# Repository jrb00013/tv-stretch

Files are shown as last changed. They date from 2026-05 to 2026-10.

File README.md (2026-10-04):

# tv-stretch

Room-aware TV coordination: a **FastAPI** server plus **ESP32** nodes that attach to each TV’s HDMI CEC bus. The stack orchestrates which room is “active” and sends control-plane commands (power, input, CEC keys). It does **not** sync protected streaming playheads; see [docs/ARCHITECTURE.md](docs/ARCHITECTURE.md).

## Repository layout

| Path | Purpose |
|---|---|
| `docs/` | Architecture, BOM, component datasheets notes, CEC, mechanical |
| `hardware/kicad/` | KiCad 8 schematic and PCB |
| `hardware/cad/` | Enclosure source and `exports/enclosure.step` |
| `firmware/tv-stretch-node/` | ESP-IDF firmware (ESP32-C3 target) |
| `server/` | FastAPI + SQLite (SQLModel), WebSocket device gateway |

## Quickstart (API)

```bash
cd server
python3 -m venv .venv
source .venv/bin/activate
pip install -e ".[dev]"
export TV_STRETCH_DATABASE_URL="sqlite:///./tv_stretch.db"
uvicorn app.main:app --reload --host 0.0.0.0 --port 8000
```

Open `http://localhost:8000/` (redirects to the control UI) or `http://localhost:8000/docs` for OpenAPI.

**Browser control UI** (`/ui/`): sticky section nav, API **version chip** (from `/health/ready`), **diagnostics** (`GET /diagnostics/overview` and per-home **live** sockets), **spatial maps** + **occupancy** lab (`/spatial/maps`, `POST /presence/occupancy`), dark-themed **bootstrap**, authenticated **REST**, **app** and **device** WebSocket labs, **log** export (download + **Ctrl+Shift+S**) and clear (**Ctrl+Shift+L**). Assets: `server/static/css/`, `server/static/js/`, `server/static/assets/favicon.svg`. Full protocol: [docs/API.md](docs/API.md). Provisioning + OTA: [docs/PROVISIONING_AND_OTA.md](docs/PROVISIONING_AND_OTA.md).

Server package version is **0.6.1** (`pyproject.toml` / `TV_STRETCH_*` defaults).

### Coordinator capabilities

| Area | What it does | Key routes |
|---|---|---|
| Handoff | REST / app-WebSocket / sensor-driven handoffs, standby of other TVs | `POST /sessions/handoff`, `/ws/app` |
| Delivery | Every `command_batch` tracked to node acks, exponential-backoff retry, dead letters | `GET /sessions/batches` |
| Replay safety | `Idempotency-Key` on the mutating session endpoints | `Idempotency-Key:` header |
| Room policy | Per-room volume cap, mute-on-handoff, preferred input, standby opt-out | `GET/PUT/DELETE /rooms/{id}/policy` |
| Quiet hours | Per-home do-not-disturb window; people can override, sensors cannot | `GET/PUT/DELETE /quiet-hours` |
| Presence tuning | Dwell hysteresis + vacancy release so sensors do not thrash the TVs | `GET /presence/hysteresis` |
| Content | Catalogue behind `content_ref`, play stats, now-playing | `GET /content`, `GET /sessions/now-playing` |
| Firmware | Per-node rollout status against a target version | `GET/PUT/DELETE /ota/rollout` |
| Events | Time-window queries, cursor pagination, age-based pruning | `GET/DELETE /sessions/events` |
| Webhooks | Signed (HMAC) outbound events with retry and delivery stats | `GET/POST /webhooks` |
| Metrics | Prometheus text format: HTTP, sockets, batch depth, node health | `GET /metrics` |

### Environment variables

| Variable | Default | Purpose |
|---|---|---|
| `TV_STRETCH_PRESENCE_HANDOFF_MIN_CONFIDENCE` | `0.65` | Minimum occupancy confidence to trigger a handoff |
| `TV_STRETCH_PRESENCE_DWELL_SECONDS` | `0` (off) | Continuous occupancy required before a sensor-driven handoff |
| `TV_STRETCH_PRESENCE_DWELL_MAX_GAP_SECONDS` | `30` | Longer reporting gap restarts the dwell timer |
| `TV_STRETCH_PRESENCE_RELEASE_SECONDS` | `0` (off) | Sustained vacancy in the active room → TVs stand by |
| `TV_STRETCH_DATABASE_URL` | `sqlite:///./tv_stretch.db` | SQLAlchemy database URL |
| `TV_STRETCH_CORS_ORIGINS` | `*` | Comma-separated allowed origins |
| `TV_STRETCH_PUBLIC_BASE_URL` | `http://127.0.0.1:8000` | Base URL used in OTA manifest URLs |
| `TV_STRETCH_OTA_FIRMWARE_PATH` / `_VERSION` | — / `0.6.1` | Hosted firmware binary and the version it reports |
| `TV_STRETCH_MQTT_ENABLED` / `_BROKER_URL` / `_BROKER_PORT` / `_PREFIX` | `true` / `localhost` / `1883` / `tvstretch` | Optional MQTT mirroring |

Quiet hours and room policies are per-home rows configured over the API, not env vars.
Full protocol and semantics: [docs/API.md](docs/API.md).

From the repo root, `./scripts/dev.sh` or `make dev` runs uvicorn with a local SQLite DB (after `pip install -e ".[dev]"` in `server/`).

Optional env vars: copy `server/.env.example` → `server/.env`. Example curls for spatial + occupancy: `scripts/spatial-presence-examples.sh` (set `TOKEN`, optionally `BASE`).

**Breaking note (0.2+):** `Home` rows require `control_token`. Delete old `tv_stretch.db` or recreate homes after upgrading.

### Docker

```bash
docker compose up --build
```

API on `http://localhost:8000`. Mosquitto is included for optional MQTT experiments; the default device transport is WebSocket.

## Firmware

Requires [ESP-IDF](https://docs.espressif.com/projects/esp-idf/) v5.2+.

```bash
cd firmware/tv-stretch-node
idf.py set-target esp32c3
idf.py build
idf.py -p /dev/ttyUSB0 flash monitor
```

Set WiFi and server URL via `idf.py menuconfig` → **TV Stretch Node Configuration**, or NVS keys documented in `firmware/tv-stretch-node/README.md`.

## Hardware

- KiCad project: `hardware/kicad/tv-stretch-node/`
- Gerber export: see `hardware/kicad/tv-stretch-node/exports/README.md`
- Enclosure STEP: `hardware/cad/enclosure/exports/enclosure.step` (regenerate with `scripts/generate_enclosure_step.py` if needed)

## License

MIT — see [LICENSE](LICENSE).

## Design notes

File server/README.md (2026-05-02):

# tv-stretch server

FastAPI coordinator: REST for provisioning and session control; WebSockets for device command batches.

## Run locally

```bash
python3 -m venv .venv
source .venv/bin/activate
pip install -e ".[dev]"
export TV_STRETCH_DATABASE_URL="sqlite:///./tv_stretch.db"
uvicorn app.main:app --reload --host 0.0.0.0 --port 8000
```

## Docker

From repo root: `docker compose up --build`.

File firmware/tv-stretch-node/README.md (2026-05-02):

# tv-stretch-node firmware

ESP-IDF **5.2+** project targeting **ESP32-C3**.

## Build

```bash
export IDF_PATH=/path/to/esp-idf
. $IDF_PATH/export.sh
cd firmware/tv-stretch-node
idf.py set-target esp32c3
idf.py menuconfig   # TV Stretch Node Configuration
idf.py build
```

## Flash

```bash
idf.py -p /dev/ttyUSB0 flash monitor
```

## NVS keys (optional overrides)

Use `nvs_set_str` via a small flasher or `idf.py nvs-set` if configured:

| Key | Purpose |
|-----|---|
| `wifi_ssid` | WiFi SSID |
| `wifi_pass` | WiFi password |
| `ws_url` | `ws://host:8000/ws/device` |
| `api_key` | Device bearer token |
| `room_id` | UUID string |
| `home_id` | UUID string |

Namespace: `tvstretch`.

## Features (0.2)

- Wi‑Fi STA with **wait-for-IP** before WebSocket connect.
- **Status LED** pulse on each `command_batch` (Kconfig `TVS_STATUS_LED_ENABLE` / GPIO).
- CEC commands: `cec_broadcast_ping`, `cec_active_source` (opcode `0x82` + physical address), `cec_standby`, `cec_send_raw`, `policy` (logged), `noop`.
- Sends **ack** after each batch with server `batch_id`.
- Reports `CONFIG_TVS_FW_VERSION` in `hello`.

## WebSocket protocol

See [docs/ARCHITECTURE.md](../../docs/ARCHITECTURE.md) and [docs/API.md](../../docs/API.md). Messages are JSON with `"v":1`.

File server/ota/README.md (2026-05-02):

# OTA artifacts (optional)

Place a built ESP-IDF binary here (e.g. copy `build/tv-stretch-node.bin` after `idf.py build`) and point the server at it:

```bash
export TV_STRETCH_OTA_FIRMWARE_PATH="$PWD/server/ota/tv-stretch-node.bin"
export TV_STRETCH_OTA_FIRMWARE_VERSION="0.3.0"
export TV_STRETCH_PUBLIC_BASE_URL="http://192.168.1.10:8000"
```

- `GET /ota/manifest` returns JSON with `version` and `url` for devices.
- `GET /ota/firmware.bin` streams the file.

Devices can pull via coordinator command:

```json
{"cmd":"ota_pull","payload":{"manifest_url":"http://192.168.1.10:8000/ota/manifest","only_if_version_differs":true}}
```

or direct URL:

```json
{"cmd":"ota_pull","payload":{"url":"http://192.168.1.10:8000/ota/firmware.bin"}}
```

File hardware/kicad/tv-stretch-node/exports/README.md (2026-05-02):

# KiCad exports

## Gerbers

From KiCad **pcbnew**:

1. **File → Fabrication Outputs → Gerbers (.ger)**
2. Include: `F.Cu`, `B.Cu`, `Edge.Cuts`, `F.Mask`, `B.Mask`, `F.Silkscreen`, `B.Silkscreen`
3. **Drill Files** separately if required by fab

Optional: `kicad-cli pcb export gerbers ...` (KiCad 7+ CLI).

## STEP (PCB 3D)

**File → Export → STEP** with component models enabled once footprints are placed.

Save as `exports/pcb.step` (gitignored if large) or attach to releases.

## Netlist

Use **Tools → Update PCB from Schematic** after completing symbols and footprints.

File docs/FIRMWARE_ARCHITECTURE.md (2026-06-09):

# tv-stretch-node Firmware Architecture

**Target:** ESP32-C3 (RISCV 32-bit single-core, 400 KB SRAM, 4 MB flash)  
**Framework:** ESP-IDF 5.2+  
**Protocol:** CEC bit-bang on GPIO + WebSocket JSON control-plane

---

## 1. System Overview

Each TV in a room gets an ESP32-C3 node wired to its HDMI CEC pin (pin 13). The node connects to the coordinator server via WebSocket and executes HDMI-CEC commands over a bit-banged GPIO line. There is no HDMI input switching or EDID emulation — this is purely a control-plane bridge.

```
┌─────────────────┐     WebSocket      ┌──────────────────┐
│  Coordinator    │ ◄────────────────► │  ESP32-C3 Node   │
│  (FastAPI)      │   JSON/v1 protocol │  (tv-stretch-node)│
└─────────────────┘                    └────────┬─────────┘
                                                 │ GPIO (open-drain)
                                                 ▼
                                         ┌──────────────────┐
                                         │  TV HDMI CEC pin │
                                         └──────────────────┘
```

---

## 2. State Machine

The node lifecycle is driven by a finite state machine in `core/tvs_state.c`:

```
COLD_START
    │
    ├── PROVISIONING ──── (SoftAP + HTTP portal, blocks)
    │
    ├── WIFI_CONNECT ──── WiFi STA started
    │       │
    │       └── WIFI_WAIT ──── waiting for DHCP
    │               │
    │               └── WS_CONNECT ──── WebSocket client started
    │                       │
    │                       ├── WS_CONNECTED ──── hello sent, ready
    │                       │
    │                       └── DISCONNECTED ──── WS dropped, reconnecting
    │
    ├── ERROR ──── unrecoverable fault
    │
    └── DEEP_SLEEP ──── low-power mode (future)
```

State transitions drive LED patterns and enable/disable subsystems.

---

## 3. Boot Sequence

```
app_main()
    │
    ├── nvs_flash_init()
    │       └── NVS recovery (erase + retry if corrupted)
    │
    ├── tvs_led_init() ──── LED task starts (BOOT pattern)
    │
    ├── tvs_watchdog_init() ──── esp_task_wdt, 30s timeout
    │
    ├── tvs_state_init() ──── state machine + change callback
    │
    ├── tvs_cec_init() ──── CEC TX GPIO (open-drain)
    ├── tvs_cec_rx_init() ──── CEC RX GPIO interrupt + ring buffer
    ├── tvs_cec_proto_init() ──── CEC protocol parser
    │
    ├── tvs_cmd_queue_init() ──── command queue with retry
    ├── tvs_health_init() ──── health counters
    │
    ├── esp_netif_init() + esp_event_loop_create_default()
    │
    ├── [CONFIG_TVS_HTTP_PROVISIONING] ──Provisioning check──┐
    │       └── NVS provisioned?                              │
    │           ├── NO  → tvs_prov_run_http_setup()           │
    │           │         (state → PROVISIONING)              │
    │           └── YES → continue                            │
    │                                                         │
    ├── Read NVS (tvstretch namespace)                       │
    │       ├── wifi_ssid / wifi_pass                        │
    │       ├── ws_url / api_key                             │
    │       ├── room_id / home_id                            │
    │                                                         │
    ├── tvs_wifi_start_sta(ssid, pass)                       │
    │       └── state → WIFI_CONNECT                         │
    │                                                         │
    ├── tvs_cec_rx_start() ──── enable CEC RX ISR            │
    │                                                         │
    ├── cmd_queue_task ──── processes queued commands         │
    │                                                         │
    ├── [CONFIG_TVS_OTA_AUTO_CHECK_ON_BOOT]                  │
    │       └── Spawns boot_ota_task (optional)              │
    │                                                         │
    ├── tvs_ws_start() ──── WebSocket client                 │
    │       └── state → WS_CONNECT                            │
    │       └── on_connect → state → WS_CONNECTED + send hello│
    │                                                         │
    ├── heartbeat_task ── every 25s if WS_CONNECTED          │
    ├── health_task ──── every 60s logs telemetry            │
    │                                                         │
    └── main loop ──── feeds watchdog every 5s               │
```

---

## 4. Module Map

| Module | File(s) | Purpose |
|---|---|---|
| **Main** | `app_main.c` | Boot sequence, task spawning, state wiring |
| **State Machine** | `core/tvs_state.c`, `core/tvs_state.h` | Finite state machine with change callback |
| **Command Queue** | `core/tvs_cmd_queue.c`, `core/tvs_cmd_queue.h` | Retry-capable command queue with ACK/NACK |
| **Protocol** | `proto/tv_stretch_proto.h` | Constants (`TVS_PROTO_VER`), message type enum, command struct |
| **CEC TX** | `cec/cec_bitbang.c`, `cec/cec_bitbang.h` | Bit-banged CEC transmit using esp_rom_delay_us |
| **CEC RX** | `cec/cec_rx.c`, `cec/cec_rx.h` | GPIO interrupt edge capture + ring buffer + software decode |
| **CEC Proto** | `cec/cec_proto.c`, `cec/cec_proto.h` | CEC opcode parsing, device discovery, bus scan |
| **WiFi** | `net/tvs_wifi.c`, `net/tvs_wifi.h` | STA mode with event-driven connect/reconnect |
| **WebSocket** | `net/ws_client.c`, `net/ws_client.h` | esp_websocket_client wrapper, header injection, connect callback |
| **OTA** | `ota/tvs_ota.c`, `ota/tvs_ota.h` | HTTP/HTTPS OTA from URL or manifest JSON |
| **LED** | `sys/tvs_led.c`, `sys/tvs_led.h` | LED pattern engine (BOOT, CONNECTING, CONNECTED, etc.) |
| **Health** | `sys/tvs_health.c`, `sys/tvs_health.h` | Telemetry counters (RSSI, frame counts, heap, uptime) |
| **Watchdog** | `sys/tvs_watchdog.c`, `sys/tvs_watchdog.h` | ESP-TASK-WDT wrapper |
| **Provisioning** | `prov/prov_http.c`, `prov/prov_http.h` | SoftAP + HTTP capture portal |
| **NVS** | `prov/tvs_nvs.c`, `prov/tvs_nvs.h` | Provisioned-state check (`nvs_get_u8`) |

---

## 5. CEC Driver Design

### 5.1 Transmit (`cec_bitbang.c`)

Implements the HDMI-CEC physical layer using bit-banged GPIO with spin-loop timing.

#### Timing (microseconds)

| Signal | Low (us) | High (us) |
|---|---|---|
| Start bit | 3700 | 800 |
| Logic 0 | 1500 | 900 |
| Logic 1 | 600 | 600 |

#### Frame format

```
[Start Bit] [Header Byte: initiator<<4 | destination] [Data Bytes...] [EOM bit per byte]
```

- Each byte is 8 bits LSB-first + 1 EOM bit + ACK slot
- The follower is expected to pull the ACK slot low; this driver uses a fixed delay for the ACK window
- No arbitration or retry logic (single-talker topology assumed)
- Before each frame, `tvs_cec_set_tx_active(true)` suppresses RX echo detection

### 5.2 Receive (`cec_rx.c`)

GPIO interrupt-based edge capture with software bit decoding.

- GPIO `INTR_ANYEDGE` ISR pushes timestamps into a 128-entry ring buffer
- Dedicated decode task (`cec_rx`) pops edges and reconstructs bits/frames
- Start bit detection (`low=3000-4500us, high=600-1100us`) triggers frame assembly
- Frame timeout after 5ms of bus inactivity
- `s_tx_active` flag suppresses echo during local TX
- Completed frames are passed to the registered callback (`tvs_cec_rx_cb`)
- Frame counter exposed for health telemetry

### 5.3 Protocol Layer (`cec_proto.c`)

Parses received CEC frames and maintains a device table:

- Tracks 16 logical addresses with physical address, device type, OSD name, vendor ID, power status
- Responds to `REPORT_PHYSICAL_ADDR`, `REPORT_POWER_STATUS`, `SET_OSD_NAME`, `DEVICE_VENDOR_ID`, `ACTIVE_SOURCE`, `STANDBY`
- Bus scan: polls all 15 addresses with `GIVE_PHYSICAL_ADDR`, `GIVE_OSD_NAME`, `GIVE_DEVICE_POWER_STATUS`
- Frames that are not protocol-internal are forwarded to the application callback

---

## 6. WebSocket Protocol

### Connection

The node connects to `ws://<coordinator>/ws/device` with custom HTTP headers:

```
Authorization: Bearer <api_key>
X-TV-Stretch-Home: <home_uuid>
X-TV-Stretch-Room: <room_uuid>
```

### Messages (all JSON with `"v": 1`)

**Node → Server:**

| Type | Frequency | Payload |
|---|---|---|
| `hello` | Once on connect | `{node: {room_id, home_id, fw}}` |
| `heartbeat` | Every 25s | None |
| `ack` | After each batch | `{batch_id, ok}` |
| `event` | On CEC RX / errors | `{payload: {kind, raw}}` |

**Server → Node:**

| Type | Purpose |
|---|---|
| `command_batch` | Array of commands with batch_id |

---

## 7. Command Dispatch

Commands arrive in `command_batch` messages and are enqueued into `tvs_cmd_queue`. The `cmd_queue_task` dequeues and dispatches them:

| cmd | Action |
|-----|---|
| `noop` | Log, no-op |
| `policy` | Log (server-side enforcement) |
| `ota_pull` | Start OTA from URL or manifest |
| `cec_broadcast_ping` | Send 0x83 frame |
| `cec_standby` | Send `<Standby>` (0x36) |
| `cec_active_source` | Send `<Active Source>` (0x82 + addr) |
| `cec_user_control` | Send `<User Control Pressed>` (0x44 + key) |
| `cec_set_stream_path` | Send `<Set Stream Path>` (0x86 + addr) |
| `cec_send_raw` | Send arbitrary CEC frame from byte array |
| `scan_bus` | Initiate CEC bus device discovery |

After all commands in a batch are processed, an `ack` is sent back.

---

## 8. LED Patterns

| State | Pattern |
|---|---|
| BOOT | Fast blink (200ms on/off) |
| CONNECTING | Slow blink (50ms on, 950ms off) |
| CONNECTED | Long pulse (100ms on, 2900ms off) |
| COMMAND | Quick flash (40ms on) |
| ERROR | Rapid blink (100ms on/off) |
| OTA | Toggle (500ms on/off) |
| OFF | Solid off |

---

## 9. Health Telemetry

The `health_task` logs every 60s (configurable via `TVS_HEALTH_INTERVAL`):

- Uptime in seconds
- WiFi RSSI
- CEC TX/RX frame counts
- WebSocket reconnection count
- Command queue depth
- Free heap / minimum free heap

---

## 10. OTA Update

Two mechanisms:

1. **Direct URL:** `ota_pull` with `{"url": "http://.../firmware.bin"}`  
   Downloads and applies via `esp_https_ota`

2. **Manifest URL:** `ota_pull` with `{"manifest_url": "http://.../manifest.json"}`  
   Fetches `{"version": "x.y.z", "url": "..."}`, optionally skips if version matches `CONFIG_TVS_FW_VERSION`

OTA uses dual-OTA partition table (2 × 1.66 MB slots). On success, `esp_restart()` boots into the new slot.

---

## 11. Provisioning

Optional HTTP-based provisioning (disabled by default, enable via `TVS_HTTP_PROVISIONING` Kconfig):

1. On first boot (NVS `provisioned != 1`), starts SoftAP `tv-stretch-setup`
2. HTTP server on `192.168.4.1:80` serves a capture portal form
3. POST `/save` writes WiFi/coordinator settings to NVS and sets `provisioned=1`
4. Device reboots into normal operation

---

## 12. Watchdog

ESP-TASK-WDT with configurable timeout (default 30s). The main loop feeds every 5s. If any task hangs for longer than the timeout, the watchdog panics and triggers a reboot.

---

## 13. Memory & Task Layout

| Task | Stack | Priority | Function |
|---|---|---|---|
| `main` | (default) | 1 | Boot, then watchdog feed loop |
| `tvs_led` | 2048 | 1 | LED pattern oscillator |
| `cec_rx` | 4096 | 8 | CEC edge decode |
| `cmdq` | 4096 | 6 | Command queue dispatch |
| `boot_ota` | 8192 | 3 | Boot-time OTA check (optional) |
| `ota` | 10240 | 5 | OTA download task |
| `hb` | 3072 | 5 | Heartbeat sender |
| `health` | 3072 | 2 | Telemetry logger |
| WiFi/WS | (IDF internal) | — | Event loop, WebSocket RX |

---

## 14. Build & Test

```bash
# Standard build
idf.py set-target esp32c3
idf.py menuconfig
idf.py build

# Flash and monitor
idf.py -p /dev/ttyUSB0 flash monitor

# Unity unit tests (on-target)
idf.py test

# Integration tests (requires pytest-embedded)
pip install pytest-embedded-serial-esp
pytest firmware/tv-stretch-node/pytest_tv_stretch_node.py \
    --embedded-services esp,idf \
    --app firmware/tv-stretch-node/build
```

---

## 15. Configuration (Kconfig)

See `main/Kconfig.projbuild` for all options. Key settings:

| Option | Default | Notes |
|---|---|---|
| `TVS_CEC_LOGICAL_ADDR` | 4 | CEC logical address claimed on bus |
| `TVS_CEC_GPIO` | 4 | CEC output pin |
| `TVS_CEC_RX_ENABLE` | y | Enable CEC receive path |
| `TVS_STATUS_LED_GPIO` | 8 | Activity LED pin |
| `TVS_HEALTH_INTERVAL` | 60s | Health telemetry log interval |
| `TVS_WATCHDOG_TIMEOUT` | 30s | Task watchdog timeout |
| `TVS_FW_VERSION` | 0.4.0 | Semver reported to coordinator |
| `TVS_HTTP_PROVISIONING` | n | Enable SoftAP setup portal |
| `TVS_OTA_AUTO_CHECK_ON_BOOT` | n | Auto-OTA on version mismatch |

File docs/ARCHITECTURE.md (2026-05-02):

# Architecture

## Goals

- **Coordinator**: single source of truth for which **room** should have the “focused” TV.
- **Nodes**: one device per TV, connected to the **HDMI CEC** line, receiving commands over **WiFi** (WebSocket to the server).
- **Clients**: apps over **`/ws/app`**, REST handoffs, or **optical / SLAM pipelines** via **`POST /presence/occupancy`** (room + confidence).

## Honesty boundary

Commercial streaming apps do not expose a supported API for **frame-accurate** resume across TVs. This project implements:

- Session metadata you control (`content_ref`, `transport`).
- TV **control plane**: CEC messages, power, input selection.
- Orchestration: **standby or focus** policies when the active room changes.

## System diagram

```mermaid
flowchart TB
  subgraph cloud [Home_LAN]
    API[FastAPI_server]
    DB[(SQLite)]
    API --> DB
  end
  Phone[Mobile_or_sensor_client]
  Slam[Optical_SLAM_or_presence_rig]
  N1[Node_room_A]
  N2[Node_room_B]
  TV1[TV_A]
  TV2[TV_B]
  Phone -->|REST_or_WS| API
  Slam -->|POST_/presence/occupancy| API
  N1 <-->|WSS_device| API
  N2 <-->|WSS_device| API
  N1 <-->|HDMI_CEC| TV1
  N2 <-->|HDMI_CEC| TV2
```

## Message flow

1. Client sets **active session** (`home_id`, `active_room_id`, optional `content_ref`) — via REST, **`/ws/app`**, or **`POST /presence/occupancy`** when localization confidence exceeds the configured threshold.
2. **Coordinator** computes a **command batch**:
   - `focus` for the node in `active_room_id`.
   - Optional `standby_others` or `cec_user_control` for non-active nodes (policy flags).
3. Server pushes JSON over **`/ws/device`** to connected nodes for that `home_id`.
4. Node applies CEC or logs if CEC is disabled in dev.

## WebSocket protocol (summary)

- **Device → server**: `hello` (api_key, node_id, firmware version), `heartbeat`, `ack`, `event` (e.g. `cec_rx` debug).
- **Server → device**: `command_batch` with ordered commands: `cec_send`, `power_toggle`, `noop`, etc.

Schema version field: `v` in each message (currently `1`).

## Security

- **Per-node API key** (stored in NVS). Rotate via re-provisioning.
- **Home `control_token`**: returned on `POST /homes` and `POST /bootstrap/...`; required for **`/ws/app`** (presence / handoff from a companion app). Treat like a password; rotate with `POST /homes/{id}/rotate-control-token`.
- Production: TLS termination (reverse proxy), no anonymous MQTT.

## Risks

- **CEC** behavior varies by TV vendor; physical address and opcodes may need tuning.
- **HDMI compliance** and trademark if you productize a dongle—consult qualified legal/compliance review.
- WiFi latency and reconnects: firmware must **buffer** one batch and **dedupe** by `batch_id`.

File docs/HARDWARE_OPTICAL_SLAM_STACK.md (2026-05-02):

# Optical SLAM, room occupancy, and the coordinator

This document ties **custom PCB / optical sensing**, **house-scale mapping (SLAM or surrogate)**, **person-in-room estimation**, and the **tv-stretch FastAPI server** so TVs follow the user via CEC handoffs.

It is an architecture guide—not a turnkey SLAM implementation. Pick compute where your algorithm requires it (often **SBC class**, not the ESP32 CEC dongle alone).

## Roles

| Layer | Responsibility |
|---|---|
| **Mapping** | Produce a metric or topological map with **room segments** aligned (manually or automatically) to logical `Room` UUIDs already provisioned in the coordinator (`POST /rooms`, bootstrap). |
| **Localization** | Estimate camera / rig pose in the map; derive **which room polygon** contains the user (point-in-polygon or classifier). |
| **Confidence** | Emit a scalar **0–1** confidence before acting (tracking quality, occlusion, multi-hypothesis spread). |
| **Coordinator** | `POST /presence/occupancy` with `room_id` + `confidence`. Above `TV_STRETCH_PRESENCE_HANDOFF_MIN_CONFIDENCE`, runs the same path as REST/WebSocket handoff → **`command_batch`** to HDMI nodes → **switch inputs / policy** on TVs. |
| **CEC nodes** | Existing **tv-stretch-node** firmware on ESP32-C3 (see KiCad project); unchanged protocol over `/ws/device`. |

## Hardware paths (examples)

### A — Wearable / handheld rig (RGB-D or stereo + IMU)

- **Compute:** Raspberry Pi 5 / Jetson Orin Nano / x86 NUC for heavy VIO/SLAM if needed.
- **Sensors:** Stereo pair or RGB-D (e.g. Intel RealSense class), **IMU** for scale and gravity alignment.
- **Radio:** Wi‑Fi to LAN; HTTPS or WSS to coordinator (browser-grade TLS via reverse proxy).
- **Custom PCB:** Sensor bracket + **USB3** hub + IMU on **I²C** to the SBC; optional battery gauge.

### B — Fixed ceiling / wall optical nodes (no full SLAM on device)

- **Per-room** depth blob or low-res occupancy grid fused on a **home server**; server-side SLAM optional.
- **Optical:** ToF arrays (e.g. **VL53L5CX**), mmWave presence (non-optical but common pairing), or narrow-FOV IR grids.
- **MCU:** ESP32-S3 for aggregation + Wi‑Fi; **not** responsible for full-house SLAM unless map is trivial.

### C — Cartographer-style LiDAR + odometry (mobile base)

- **2D LiDAR** + wheel odometry or IMU; output pose to mapping stack; room IDs assigned when crossing thresholds / doors (still map to coordinator `room_id` UUIDs).

## Map ↔ server contract

1. **Provision rooms** in the coordinator (`POST /bootstrap/home-with-rooms` or `/rooms`) so each physical room has a **stable UUID**.
2. **Upload spatial metadata** (optional but recommended): `POST /spatial/maps` with JSON under `slam.v1` (or your schema string). Store polygons, adjacency, or vendor SLAM export references for debugging and alignment.
3. **Runtime:** localization stack selects **one `room_id`** + **confidence** → `POST /presence/occupancy`.

Payload shape is intentionally loose: your SLAM stack owns the JSON under `payload`; the server stores it opaquely for tooling.

## Software integration

- **Auth:** Same **`X-Control-Token`** as other home APIs (treat like a password on TLS inside LAN).
- **Threshold:** `TV_STRETCH_PRESENCE_HANDOFF_MIN_CONFIDENCE` (default **0.65**) suppresses flaky switches.
- **Displays:** Handoff path already issues **CEC** commands via nodes; tune coordinator policies (`standby_others`) for multi-TV homes.

## Physical / safety

- **HDMI CEC** varies by TV vendor—expect lab tuning (see [CEC_NOTES.md](CEC_NOTES.md)).
- **Privacy:** cameras and continuous localization carry consent and retention obligations—document your policy.

## Related docs

- [COMPONENTS_HARDWARE.md](COMPONENTS_HARDWARE.md) — tv-stretch-node BOM-level parts.
- [BOM.md](BOM.md) — optional presence/SLAM companion bill of materials.
- [ARCHITECTURE.md](ARCHITECTURE.md) — system diagram including occupancy path.
- [API.md](API.md) — `/spatial/*`, `/presence/occupancy`.

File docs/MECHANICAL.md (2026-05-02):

# Mechanical — enclosure

## Concept

**Inline puck** enclosure: PCB + HDMI **receptacle** faces one direction; **short pigtail** or second HDMI exits toward the TV. Two **shell halves** (top/bottom) with **snap clips** or **M2 standoffs** (optional).

## Files

| File | Description |
|---|---|
| `hardware/cad/enclosure/tv_stretch_enclosure.py` | build123d source (Python) |
| `hardware/cad/enclosure/exports/enclosure.step` | Hollow shell (outer box minus cavity) for printing / machining |

## Regenerating STEP

```bash
pip install build123d
python3 scripts/generate_enclosure_step.py
```

Default outer box (placeholder geometry) targets ~**80 × 40 × 22 mm**; edit parameters in the script to match your PCB.

## 3D printing

- **Orientation:** Largest flat face on build plate; avoid overhangs on clip features.
- **Tolerance:** Add **0.25–0.4 mm** clearance between shell and connector bodies.
- **Material:** PETG or ABS for heat near TV vents; PLA acceptable for prototypes.

## Strain relief

Use a **zip tie channel** around the HDMI pigtail exit (parametric in script) or heat-shrink anchor.

## KiCad PCB STEP

When the PCB is routed in KiCad: **File → Export → STEP** (include components). Store under `hardware/kicad/tv-stretch-node/exports/` if desired.

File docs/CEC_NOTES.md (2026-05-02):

# HDMI-CEC notes (tv-stretch-node)

## Pin reference (Type A HDMI)

| Pin | Name | Node connection |
|-----|---|---|
| 13 | CEC | MCU GPIO (open-drain), ESD diode |
| 17 | DDC/CEC GND | Ground |
| 18 | +5V | Optional sense / tie per design |

**Do not** connect TMDS pairs to the MCU; this design is **CEC-only**, not a video path.

## Electrical

- CEC is **single-wire**, **open-drain**, typically **3.3 V** I/O on modern implementations.
- Bit timing: start bit + data blocks per **HDMI 1.4b / CEC 1.4** (Consult HDMI Licensing / IEC 62388-1 for product compliance).
- Use **scope or logic analyzer** when bringing up a new TV.

## Firmware subset

The in-tree driver implements a **minimal** subset sufficient for demos:

- Low-level **start bit**, **byte TX/RX** with ACK bit handling (simplified).
- Helpers for **broadcast** and **directed** frames.
- Example opcodes: `<Give Physical Address>`, `<Report Physical Address>`, `<Active Source>`, `<Set Stream Path>`, `<Standby>`, `<User Control Pressed>` (power, select).

TVs may require correct **logical** and **physical** addresses. Set `physical_address` in Kconfig to match topology (e.g. `0x2000`).

## Compatibility

- Some TVs disable CEC unless enabled in menus (Samsung Anynet+, Sony Bravia Sync, etc.).
- AVRs in the path change routing; you may need to address the **receiver** instead of the TV.

## References (external)

- Community implementations (license differs): ESPHome native HDMI-CEC projects.
- HDMI organization specifications (paid / license agreement) for shipping products.

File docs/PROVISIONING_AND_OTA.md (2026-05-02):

# Provisioning and OTA

## HTTP provisioning (ESP32)

Enable **Component config → TV Stretch Node Configuration → First-boot SoftAP + HTTP provisioning UI**.

On first boot (NVS key `provisioned` ≠ 1), the device starts an access point:

- SSID / password: Kconfig `TVS_PROV_AP_SSID` / `TVS_PROV_AP_PASS` (defaults `tv-stretch-setup` / `tvstretch1`).
- Join from a phone or laptop, open **http://192.168.4.1**
- Submit Wi-Fi credentials, `ws_url` (`ws://…/ws/device`), node `api_key`, `home_id`, `room_id`.
- Device writes NVS namespace `tvstretch`, sets `provisioned=1`, reboots into STA mode.

Disable provisioning in production firmware builds once nodes are flashed, or rely on pre-provisioned NVS.

## OTA partitions

`firmware/tv-stretch-node/partitions.csv` defines **dual OTA** app slots. Flash with `idf.py flash` as usual; the running image must be linked for OTA (see ESP-IDF OTA docs).

`sdkconfig.defaults` sets `CONFIG_ESP_HTTPS_OTA_ALLOW_HTTP=y` so **LAN HTTP** URLs work. Do not expose unauthenticated OTA endpoints on the public internet.

## Coordinator OTA

See [server/ota/README.md](../server/ota/README.md). Configure `TV_STRETCH_OTA_FIRMWARE_PATH` and `TV_STRETCH_PUBLIC_BASE_URL`.

## Device-side triggers

- **Boot:** optional `TVS_OTA_BOOT_MANIFEST_URL` + `TVS_OTA_AUTO_CHECK_ON_BOOT` (off by default).
- **Command:** `ota_pull` with `url` or `manifest_url` (see server README).

Firmware version string comes from Kconfig `TVS_FW_VERSION` and is compared to manifest `version` when using `only_if_version_differs`.

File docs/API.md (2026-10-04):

# HTTP and WebSocket API

Base URL: `http://localhost:8000` (or your host). OpenAPI UI: `/docs`. Root `/` redirects to `/ui/` (browser lab).

## Authentication model

- **Nodes** (TV hardware): `Authorization: Bearer <node_api_key>` and `X-TV-Stretch-Home: <home_uuid>` on **`/ws/device`**.  
  For **browser testing** (no custom headers), the same credentials may be passed as query parameters:  
  `ws://host/ws/device?home_id=<uuid>&token=<api_key>` (or `api_key=` instead of `token=`).

- **Apps** (phone / automation): `X-Control-Token: <home.control_token>` on REST routes under `/homes`, `/rooms`, `/nodes`, `/sessions`, `/spatial`, `/presence`, etc.

- **App WebSocket** `/ws/app`: `Authorization: Bearer <control_token>` + `X-TV-Stretch-Home: <home_uuid>`, **or** query params `?home_id=<uuid>&token=<control_token>` (required for browsers).

REST endpoints for provisioning (`POST /homes`, `POST /bootstrap/...`) are unauthenticated by default (home LAN / dev). Put the API behind a reverse proxy and TLS before exposing to the internet.

## Bootstrap a home

```bash
curl -sS -X POST http://localhost:8000/bootstrap/home-with-rooms \
  -H 'Content-Type: application/json' \
  -d '{"home_name":"loft","room_names":["living","kitchen","bedroom"]}'
```

Save `home.control_token`, `home.id`, and each `rooms[].id`.

## Register a node per TV

Requires the home control token:

```bash
curl -sS -X POST http://localhost:8000/nodes/register \
  -H 'Content-Type: application/json' \
  -H "X-Control-Token: <CONTROL_TOKEN>" \
  -d '{"room_id":"<ROOM_UUID>","name":"living-tv"}'
```

Save `api_key` into firmware NVS (or Kconfig for dev).

## Handoff (REST)

```bash
curl -sS -X POST http://localhost:8000/sessions/handoff \
  -H 'Content-Type: application/json' \
  -H "X-Control-Token: <CONTROL_TOKEN>" \
  -d '{"active_room_id":"<ROOM_UUID>","content_ref":"demo","standby_others":true}'
```

- `standby_others` (default `true`): when true, the coordinator emits a `policy` command for non-active TVs; when `false`, that step is skipped.

Response includes `batch_id` and expanded `commands` pushed to connected nodes.

## Handoff (app WebSocket)

Connect to `ws://localhost:8000/ws/app` with headers or `?home_id=&token=` as above.

Send presence:

```json
{"v":1,"type":"presence","active_room_id":"<ROOM_UUID>","content_ref":"optional","standby_others":true}
```

Optional: query current session state without HTTP:

```json
{"v":1,"type":"get_session"}
```

Server replies:

```json
{"v":1,"type":"session_state","home_id":"...","active_room_id":null,"content_ref":null,"updated_at":null}
```

After a successful presence handoff:

```json
{"v":1,"type":"handoff_applied","batch_id":"..."}
```

Ping:

```json
{"v":1,"type":"ping"}
```

→ `{"v":1,"type":"pong"}`

## Device WebSocket protocol

Devices connect to `ws://host/ws/device` with node `api_key` and home id (headers **or** query params as above).

**Device → server**

| type | Purpose |
|---|---|
| `hello` | First contact; may include `node.fw`, `node.room_id`, `node.home_id`. Updates `last_seen_at` and firmware version. |
| `heartbeat` | Periodic liveness; updates `last_seen_at`. |
| `ack` | After executing a `command_batch`: `batch_id`, `ok`. Logged as `device_ack`. |
| `event` | Debug / vendor hooks; payload stored in `EventLog` as `device_event`. |

**Server → device**

- `command_batch`: `{ "v":1, "type":"command_batch", "batch_id":"...", "commands":[...] }`

Schema version field: `v` (currently `1`).

## Diagnostics

- `GET /diagnostics/overview` — counts + WebSocket snapshot (connected device nodes per home).
- `GET /diagnostics/homes/{home_id}/live` — connected device sockets for that home.
- `GET /health` — liveness.
- `GET /health/ready` — DB reachability smoke check. JSON includes `version` and `presence_handoff_min_confidence` (same default as `TV_STRETCH_PRESENCE_HANDOFF_MIN_CONFIDENCE`, for UI / rig tuning).

## Webhooks

Push home events to your own HTTP endpoint (Home Assistant, a shell script, a cloud function).
Requires `X-Control-Token`. Registering an endpoint requires the control token, so only the
home owner can make the server issue outbound requests — bind that thinking to your threat
model if you ever expose the token.

| Route | Purpose |
|---|---|
| `POST /webhooks` | Register an endpoint → `201` with the **signing secret shown once** |
| `GET /webhooks`, `GET /webhooks/{id}` | List / read (never includes the secret) |
| `PATCH /webhooks/{id}` | Change `url`, `events`, `enabled` |
| `DELETE /webhooks/{id}` | Remove |
| `POST /webhooks/{id}/rotate-secret` | New secret; old signatures stop verifying |
| `POST /webhooks/{id}/test` | Send a signed `test` delivery now |

```bash
curl -sS -X POST http://localhost:8000/webhooks \
  -H 'Content-Type: application/json' -H "X-Control-Token: <CONTROL_TOKEN>" \
  -d '{"url":"https://homeassistant.local/api/tv-stretch","events":["handoff","power"]}'
```

Events: `handoff`, `power`, `cec_key`, `input_select`, `standby_all`, `handoff_suppressed`,
`command_batch_failed`. An **empty `events` list receives everything**. Unknown names → `422`.
URLs must be `http`/`https` with a host.

Payload:

```json
{
  "event": "handoff",
  "home_id": "…",
  "sent_at": "2026-06-09T21:03:48Z",
  "data": {"batch_id": "…", "room_id": "…", "content_ref": "netflix:show-1", "source": "api"}
}
```

Headers: `X-TV-Stretch-Signature`, `X-TV-Stretch-Timestamp`, `X-TV-Stretch-Event`,
`X-TV-Stretch-Delivery`.

Verify with `hmac.compare_digest` over **`timestamp.body`**:

```python
expected = "sha256=" + hmac.new(secret.encode(), f"{timestamp}.{body}".encode(), hashlib.sha256).hexdigest()
ok = hmac.compare_digest(expected, headers["X-TV-Stretch-Signature"])
```

Binding the timestamp into the signature is what makes a captured request unusable when
replayed. Reject timestamps more than ~5 minutes old.

Delivery behaviour:

- **Queued, never awaited by the request.** A slow or dead receiver cannot add latency to a
  TV handoff; a background worker drains the queue.
- Retries: 3 attempts with exponential backoff (0.5s, 1s) on transport errors and `5xx`.
  **A `4xx` is not retried** — the receiver rejected the request, and repeating it will not
  help.
- Per-endpoint `last_status`, `last_error`, `success_count`, `failure_count` and
  `last_delivery_at` are recorded on every delivery, so a dead receiver is visible via
  `GET /webhooks` rather than silently dropping events.
- Uses the stdlib `urllib` (in a thread), so delivery adds no runtime dependency.

## Metrics

`GET /metrics` — Prometheus text exposition format (`text/plain; version=0.0.4`).
Unauthenticated, like `/health` and `/diagnostics/overview`: expose it on an internal
interface or behind the reverse proxy, not on the open internet.

| Series | Type | Labels |
|---|---|---|
| `tv_stretch_http_requests_total` | counter | `method`, `path`, `status` |
| `tv_stretch_http_request_duration_seconds` | histogram | `path` |
| `tv_stretch_build_info` | gauge | `version` |
| `tv_stretch_ws_connections` | gauge | `type` = `device` \| `app` |
| `tv_stretch_command_batches` | gauge | `status` = `pending` \| `completed` \| `dead_letter` |
| `tv_stretch_nodes` | gauge | `status` = `online` \| `stale` \| `offline` \| `unknown` |
| `tv_stretch_homes` | gauge | — |

- `path` is the **route template** (`/rooms/{room_id}`), never the raw path. Labelling per
  UUID would blow up cardinality and take the scrape down with it; unmatched requests share a
  single `unmatched` bucket.
- No metric carries a `home_id` label — per-home series would multiply cardinality again. Use
  the authenticated per-home routes (`/sessions/health`, `/ota/rollout`, …) for that.
- Counters and histograms are in-process and reset on restart. Gauges (connections, batch
  depth, node health) are computed live at scrape time, so they are correct immediately after
  a restart.
- Every response also carries `X-Response-Time-Ms`.

Scrape config sketch:

```yaml
scrape_configs:
  - job_name: tv-stretch
    static_configs:
      - targets: ["192.168.1.10:8000"]
```

## OTA (firmware hosting)

- `GET /ota/manifest` — JSON `version` + `url` + `available` (`url: null` when no file is configured).
- `GET /ota/firmware.bin` — binary when `TV_STRETCH_OTA_FIRMWARE_PATH` points to a file on disk.
- `GET /ota/rollout` — **authenticated** per-node firmware status for the home (exposes node ids).
- `PUT /ota/rollout` — set the `target_version` every node should run (1–32 chars).
- `DELETE /ota/rollout` — stop tracking (`404` if none).

Set `TV_STRETCH_PUBLIC_BASE_URL` so manifest URLs are reachable from the device LAN (e.g. `http://192.168.1.10:8000`).

Nodes report `firmware_version` in their `hello` message; the rollout compares it to the target:

```json
{
  "target_version": "0.7.0",
  "manifest_version": "0.7.0",
  "manifest_matches_target": true,
  "nodes": [{"node_id": "…", "name": "living-tv", "firmware_version": "0.6.9", "status": "behind"}],
  "summary": {"total": 1, "converged": 0, "pending": 1, "ahead": 0, "unknown": 0}
}
```

| `status` | Meaning |
|---|---|
| `up_to_date` | Reported version equals the target |
| `behind` | Reported version sorts lower than the target |
| `ahead` | Reported version sorts **higher** (e.g. after rolling back a target) |
| `unknown` | No target set, the node has never reported a version, or the version has no numeric content |

- Versions compare **numerically**, not as strings: `0.10.0` is newer than `0.7.0`.
  Build metadata after `+` is ignored, so `0.9.0+build7` is still `0.9.0`.
- `manifest_matches_target: false` means the server is not serving the version you asked to
  roll out — nodes can never converge until `TV_STRETCH_OTA_FIRMWARE_VERSION` and the hosted
  binary match. It is reported rather than left for someone to debug from a stuck rollout.
- Nothing is pushed by these routes; devices pull from `/ota/manifest` on their own schedule.

## Events

`GET /sessions/events` returns recent `EventLog` rows (handoffs, device acks, device events,
`occupancy_below_threshold`, `handoff_suppressed`, `standby_all`, …). Requires `X-Control-Token`.

| Param | Meaning |
|---|---|
| `limit` | 1–500, default 50 |
| `kind` | Exact event kind (see `GET /sessions/events/kinds`) |
| `since` | ISO-8601; only events at or after this instant |
| `until` | ISO-8601; only events strictly before this instant |
| `cursor` | Keyset cursor from `X-Next-Cursor`; continues strictly before that event |

```bash
curl -sS "http://localhost:8000/sessions/events?kind=handoff&since=2026-06-09T00:00:00Z&limit=100" \
  -H "X-Control-Token: <CONTROL_TOKEN>"
```

- Timestamps **without** a timezone are read as UTC. Prefer the `Z` form — a raw `+00:00` in a
  query string decodes to a space.
- Pagination is keyset-based, so walking with `cursor` stays stable while new events arrive.
  `X-Next-Cursor` is only present when a full page was returned, and is emitted as
  `…Z` so it can be pasted straight into `?cursor=`.
- `since` after `until` → `422`.

Retention — `DELETE /sessions/events` returns `204` and `X-Deleted-Count`:

| Call | Effect |
|---|---|
| `DELETE /sessions/events` | Clear the whole log (previous behaviour) |
| `DELETE /sessions/events?older_than_seconds=3600` | Prune rows older than an age |
| `DELETE /sessions/events?before=<ISO-8601>` | Prune rows before an instant |
| both | The **stricter** (older) cutoff wins |

Rows for other homes are never touched. There is no automatic retention job yet — schedule
the prune yourself or call it from cron.

## Content library + now playing

`content_ref` has always been a free-form string on a handoff. The library gives those refs
titles, sources and play history, so "what is playing?" is answerable and the house has some
sense of what gets watched. Requires `X-Control-Token`.

| Route | Purpose |
|---|---|
| `POST /content` | Register an entry (`201`); duplicate `ref` in the same home → `409` |
| `GET /content` | List, newest first; filter with `?kind=` and/or `?ref=` |
| `GET /content/top?limit=5` | Most-played entries (never-played excluded, limit clamped 1–50) |
| `GET /content/{content_id}` | One entry |
| `PATCH /content/{content_id}` | Partial update, including `metadata` |
| `DELETE /content/{content_id}` | Remove; the `ref` becomes reusable |
| `GET /sessions/now-playing` | Active room + resolved catalogue entry |

```bash
curl -sS -X POST http://localhost:8000/content \
  -H 'Content-Type: application/json' \
  -H "X-Control-Token: <CONTROL_TOKEN>" \
  -d '{"ref":"netflix:stranger-things-s4","title":"Stranger Things S4",
       "source":"app:netflix","kind":"tv","duration_seconds":3600,
       "metadata":{"season":4,"episode":1}}'
```

- `ref` must match `^[A-Za-z0-9][A-Za-z0-9._:-]{0,63}$` — it travels in URLs and command
  payloads. It is unique per home, so two homes may use the same ref.
- **Handoffs count plays.** Every handoff whose `content_ref` matches an entry increments
  `play_count` and stamps `last_played_at`, on all three handoff paths (REST, occupancy, app
  WebSocket). The `handoff` event payload gains `content_title`.
- **Registration is never required.** An unregistered `content_ref` still works everywhere;
  `now-playing` just reports `content: null` for it. Clients must not have to pre-register
  content to move a TV.
- `now-playing` returns `{home_id, active_room_id, content_ref, content, playing_since}`;
  with no active room it returns `active_room_id: null`.

## Presence hysteresis (dwell + vacancy release)

One above-threshold reading is not evidence that somebody settled in — SLAM noise, someone
crossing the doorway, or a pet all produce one, and each switches the TV. Two opt-in
hysteresis controls sit in front of the occupancy handoff:

| Env var | Default | Effect |
|---|---|---|
| `TV_STRETCH_PRESENCE_DWELL_SECONDS` | `0` (off) | Continuous above-threshold occupancy required before a handoff fires |
| `TV_STRETCH_PRESENCE_DWELL_MAX_GAP_SECONDS` | `30` | A reporting gap longer than this restarts the dwell timer |
| `TV_STRETCH_PRESENCE_RELEASE_SECONDS` | `0` (off) | Sustained below-threshold reporting in the **active** room before the TVs stand by |

Defaults are `0` so existing behaviour is unchanged: enable them per deployment.

Dwell semantics:

- The clock starts at the first qualifying reading for a room and only advances while readings
  for **that same room** keep arriving.
- Switching target room, or a gap longer than `*_MAX_GAP_SECONDS`, restarts it.
- While waiting, `POST /presence/occupancy` returns `200` with `handoff: false`,
  `reason: "dwell"` and `dwell_remaining_seconds`. Readings are still stored; session state,
  events and command batches are untouched.
- Order of checks: threshold → quiet hours → already-active → dwell → handoff.

Vacancy release:

- Driven by the **existing** below-threshold path — no new endpoint, no new client behaviour.
  A sensor that keeps reporting the active room as empty eventually gets a `standby_all`
  command batch, and session state is cleared (`active_room_id: null`, `content_ref: null`).
- The first low reading starts the clock, so a release always needs at least two observations.
- Vacancy reported for a room that is *not* the active room never releases anything.
- Release events use kind `standby_all`; the presence release also publishes MQTT
  `standby_all` with `source: presence_release`.

- `GET /presence/hysteresis` — current candidate (`room_id`, `reports`, `confidence`,
  `first_seen_at`), `vacant_since` and the effective timings. Requires `X-Control-Token`.
- Tracker state is in-memory per home, so a restart clears a pending dwell.

## Quiet hours (do-not-disturb)

A per-home window that suppresses **automatic** TV handoffs — nobody wants the living-room TV
waking up because a presence sensor noticed movement at 03:00. Requires `X-Control-Token`.

- `GET /quiet-hours` — the stored window plus `active_now`, `minutes_remaining`, `next_transition`.
- `PUT /quiet-hours` — create or replace. `start_minute`/`end_minute` are minutes from midnight
  **UTC** (0–1439) and must differ; `weekdays` is ISO weekday numbers (`1`=Mon … `7`=Sun).
- `DELETE /quiet-hours` — remove the window.

```json
{"enabled": true, "start_minute": 1320, "end_minute": 420, "weekdays": "1,2,3,4,5,6,7"}
```

Behaviour:

| Path | During the window |
|---|---|
| `POST /sessions/handoff` | `200` with `ok: false`, `suppressed: true`, `reason: "quiet_hours"`, `batch_id: null`, no commands pushed |
| `POST /presence/occupancy` | Reading is still stored; `handoff: false`, `reason: "quiet_hours"` |
| `/ws/app` `presence` | Reply `{"v":1,"type":"handoff_suppressed","reason":"quiet_hours","minutes_remaining":N}` |

- **Override**: send `"override_quiet_hours": true` on the REST handoff (or `override_quiet_hours`
  in the app WebSocket message) when a *person* explicitly asks for a TV. Sensor-driven presence
  cannot override — it has no field for it.
- Every suppression writes a `handoff_suppressed` event with the room, source and minutes
  remaining, so "why didn't the TV turn on?" is answerable from `/sessions/events`.
- Suppressed handoffs still consume an `Idempotency-Key` and replay the suppression, not a
  later success.
- **Weekday semantics for windows that wrap midnight**: the list applies to the day the window
  *starts*, so `"weekdays": "1,2,3,4,5"` with `22:00→07:00` means quiet Monday through Friday
  night, waking up Saturday morning — not quiet again on Saturday night.
- Times are UTC. There is no per-home timezone yet; if you need local quiet hours, convert
  before writing the window.

## Per-room AV policy

Each room can carry an AV policy applied on **every** handoff into it (e.g. a kids' room
that always starts muted and capped, or a bedroom TV that must never take over the house).
Requires `X-Control-Token`; all three routes are home-scoped (`404` for another home's room).

- `GET /rooms/{room_id}/policy` — stored policy, or defaults with `updated_at: null`.
- `PUT /rooms/{room_id}/policy` — create or replace. `preferred_input` requires `input_physical_address`.
- `DELETE /rooms/{room_id}/policy` — fall back to coordinator defaults.

```json
{
  "volume_cap": 45,
  "mute_on_handoff": true,
  "preferred_input": "shield-hdmi1",
  "input_physical_address": 8192,
  "standby_on_inactive": true
}
```

Emitted commands (in order, before the room is switched active):

| Field | Command | Notes |
|---|---|---|
| `preferred_input` + `input_physical_address` | `cec_set_stream_path` | Address is a CEC physical address (`0x0000`–`0xFFFF`), not a name |
| `volume_cap` (0–100) | `cec_send_raw` → `SET_AUDIO_VOLUME` (0x41) | Mapped to 16 CEC steps, always rounding **down**, so the TV never gets louder than the cap; `0` is CEC mute |
| `mute_on_handoff` | `cec_user_control` with key `0x41` | CEC MUTE |
| `standby_on_inactive: false` | suppresses the `policy` standby step | Effective standby is `standby_others AND standby_on_inactive` |

Only command types the node firmware dispatches are emitted. The ceiling is a starting
point, not a limiter — someone can still turn the volume up with the remote afterwards.

## Idempotency keys

`POST /sessions/handoff`, `/sessions/power`, `/sessions/cec-key` and `/sessions/input-select`
accept an optional `Idempotency-Key` header (≤128 chars). A retry of the same request with the
same key returns the **original** response — same `batch_id`, same commands — and does not
push a second `command_batch` to the TVs or write a second event.

```bash
curl -sS -X POST http://localhost:8000/sessions/handoff \
  -H 'Content-Type: application/json' \
  -H "X-Control-Token: <CONTROL_TOKEN>" \
  -H 'Idempotency-Key: 9f2c-handoff-1' \
  -d '{"active_room_id":"<ROOM_UUID>"}'
```

Responses:

| Situation | Result |
|---|---|
| First use of the key | Normal response, no replay header |
| Same key, same payload, already completed | Stored response + `Idempotent-Replay: true` |
| Same key, **different** payload | `409` `Idempotency-Key was already used for a different request payload` |
| Same key, original request still in flight | `409` `a request with this Idempotency-Key is still in flight` |
| Key longer than 128 chars or blank | `400` |

Details:

- Keys are scoped **per home**; two homes may use the same key independently.
- The fingerprint covers the endpoint plus the body **with defaults resolved**
  (`{"active_room_id": …, "content_ref": null, "standby_others": true}`), so `{}` and an
  explicit `"standby_others": true` are the same request.
- Records live for 24 h, then the key is reusable. They are stored in the `idempotencyrecord`
  table (created automatically) and removed with the home.
- Omitting the header keeps the previous behaviour: every call executes.

## Command batch delivery

Every `command_batch` the server pushes is tracked until the connected nodes ack it.
Batches are **not** persisted (in-memory only, lost on restart), so lifecycle
transitions are also written to the event log as `command_batch_retry`.

- `GET /sessions/batches` — in-flight, dead-lettered and recently completed batches for the home.
- `GET /sessions/batches/{batch_id}` — one batch, or `404` when unknown / owned by another home.

```json
{
  "batch_id": "0f0c…",
  "status": "pending | retry | complete | failed",
  "attempts": 1,
  "max_attempts": 3,
  "expected_nodes": ["6b1e…", "9f42…"],
  "acked_nodes": ["6b1e…"],
  "failed_nodes": [],
  "next_attempt_at": "2026-06-09T21:10:04+00:00",
  "last_error": null
}
```

Semantics:

- `expected_nodes` is the set of nodes connected **at push time**. A batch completes when
  every expected node has acked; the first `ok: true` ack settles it when no node was connected.
- A batch with unacked nodes is redelivered with exponential backoff (2s, 4s) up to
  `max_attempts`, including batches pushed while every node was offline — a node that
  reconnects inside the window still receives them.
- `ok: false` acks (or an exhausted attempt budget) mark the batch `failed`; it stays readable
  in the dead-letter store. Dead letters and completed batches are bounded (200 / 100).

Device acks carry the same payload as before; `error` is optional:

```json
{"type":"ack","batch_id":"0f0c…","ok":false,"error":"cec timeout"}
```

## Spatial maps (SLAM / floor-plan JSON)

Authenticates with `X-Control-Token` (same as other home APIs).

- `POST /spatial/maps` — body: `{ "label": "floor1", "schema_version": "slam.v1", "payload": { ... } }`. Upserts by **label** per home.
- `GET /spatial/maps` — list map summaries (no large payload).
- `GET /spatial/maps/{map_id}` — full map including `payload`.
- `DELETE /spatial/maps/{map_id}`

## Presence / occupancy (optical SLAM → TV handoff)

- `POST /presence/occupancy` — body:

```json
{
  "room_id": "<ROOM_UUID>",
  "confidence": 0.85,
  "source": "optical_slam",
  "map_id": null,
  "pose": { "x": 0, "y": 0, "yaw": 0 },
  "content_ref": null,
  "standby_others": true
}
```

If `confidence` is **below** `TV_STRETCH_PRESENCE_HANDOFF_MIN_CONFIDENCE` (default `0.65`, overridable via env), the server **does not** hand off; response includes `"handoff": false, "reason": "below_threshold"`.

If the user is **already** in the active room, returns `"handoff": false, "reason": "already_active"`.

Otherwise runs the same coordinator path as `POST /sessions/handoff` and pushes `command_batch` to nodes.

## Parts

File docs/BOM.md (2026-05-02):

# Bill of materials — tv-stretch-node (rev A)

Columns: Ref | Qty | Manufacturer | MPN | Description | Footprint | Supplier notes

| Ref | Qty | Manufacturer | MPN | Description | Footprint | Supplier notes |
|-----|-----|---|-----|---|---|---|
| U1 | 1 | Espressif | ESP32-C3-MINI-1-N4 | Wi-Fi MCU module, 4 MB flash | Module ESP32-C3-MINI-1 | LCSC C2838500 / Mouser |
| U2 | 1 | Diodes Inc. | AP2112K-3.3TRG1 | LDO 3.3 V, 600 mA | SOT-23-5 | |
| J1 | 1 | GCT or equiv. | USB4085-GF-A | USB-C receptacle, 16-pin mid-mount | USB-C 16P | Verify CC routing |
| J2 | 1 | — | HDMI-A receptacle (SMD) | HDMI Type A female | HDMI19SMD | Match mechanical to pigtail if used |
| J3 | 1 | — | HDMI-A plug (or cable assembly) | To TV | Cable | Many builds use short pigtail from J2 |
| D1 | 1 | Nexperia | PESD5V0S1BA | ESD on CEC | SOD-323 | Optional USBLC6 for USB pair |
| R1 | 1 | — | 10k 1% | CEC pull-up to 3V3 | 0402 | HDMI spec pull-up often ~27k on bus; follow TV node design |
| R2,R3 | 2 | — | 5.1k 1% | USB-C CC resistors (Rd) | 0402 | If using “sink 5 V only” |
| C1,C2 | 2 | — | 10 µF 10 V X5R | LDO in/out | 0805 | |
| C3,C4 | 2 | — | 100 nF 50 V | Decoupling | 0402 | |
| LED1 | 1 | — | Green LED | Status | 0603 | |
| R4 | 1 | — | 1k | LED current limit | 0402 | |
| SW1 | 1 | — | Tactile | Boot / provision | 6x6mm | |
| — | 1 | — | PCB | 2-layer, 1 mm or 1.6 mm | — | Impedance not critical |

**Alternates:** ESP32-C3-WROOM-02; LDO AP7363 or TLV75533; HDMI pigtail instead of on-board plug.

**Mechanical:** screws, enclosure — see [MECHANICAL.md](MECHANICAL.md).

---

## Optional — optical SLAM / presence companion (not on CEC dongle PCB)

These parts support **mapping + localization** that calls `POST /presence/occupancy` on the coordinator. Typical builds use a **separate SBC or dev kit** plus sensors; the ESP32-C3 node remains the HDMI adapter only.

| Role | Example parts | Notes |
|---|---|---|
| Depth / RGB-D | Intel RealSense–class USB module, stereo camera pairs | Often needs USB3 + adequate PSU |
| ToF grids | VL53L5CX / VL53L8CX (I²C) | Room-scale occupancy hints without full SLAM |
| IMU | BMI270, ICM-42688-P (SPI/I²C) | Fusion with vision / VO |
| Edge ML MCU | ESP32-S3 with PSRAM | Lightweight fusion only—heavy SLAM usually on **Pi / Jetson / PC** |
| SBC | Raspberry Pi 5, Jetson Orin Nano | ORB-SLAM3, RTAB-Map, OpenVINS-class stacks |

See [HARDWARE_OPTICAL_SLAM_STACK.md](HARDWARE_OPTICAL_SLAM_STACK.md) for system wiring and [COMPONENTS_HARDWARE.md](COMPONENTS_HARDWARE.md) for the CEC node itself.

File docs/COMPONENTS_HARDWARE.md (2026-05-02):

# Hardware components (detailed)

This file describes **tv-stretch-node** (ESP32-C3 HDMI CEC dongle). For **optical SLAM / presence companion** hardware (ToF, RGB-D, SBC), see [HARDWARE_OPTICAL_SLAM_STACK.md](HARDWARE_OPTICAL_SLAM_STACK.md) and the optional BOM section in [BOM.md](BOM.md).

## U1 — ESP32-C3-MINI-1

- **Role:** Main MCU, Wi‑Fi (2.4 GHz), TLS-capable client, GPIO bit-bang CEC.
- **Supply:** 3.0–3.6 V typical; use 3.3 V LDO.
- **Antenna:** On-module PCB antenna; keep ground clearance per Espressif layout guide.
- **Footprint:** Espressif reference land pattern for MINI-1 module.
- **Notes:** GPIO4/GPIO5 often strapping; pick CEC pin per `sdkconfig` (default GPIO 4). Avoid USB pins if using USB-JTAG.

## U2 — AP2112K-3.3 (or equivalent LDO)

- **Role:** Regulate 5 V (USB VBUS) to 3.3 V.
- **Iout:** ≥ 500 mA recommended for Wi‑Fi peaks.
- **Caps:** 1–10 µF ceramic on input and output close to pins.

## J1 — USB-C receptacle

- **Role:** 5 V power only for v1 (no USB data required).
- **CC:** 5.1 kΩ Rd to GND on each CC line for **UFP sink**.
- **ESD:** Optional TVS array on D+/D- if data lines routed later.

## J2/J3 — HDMI connector / pigtail

- **Role:** Electrical access to **CEC** (pin 13), **DDC/CEC GND** (pin 17), optional **+5 V** (pin 18) for “connected” sense.
- **Wiring:** CEC is **open-drain**, ~3.3 V logic; MCU GPIO must be **open-drain** or external FET if required.
- **ESD:** Protect CEC line near connector (D1).

## D1 — PESD5V0S1BA (CEC ESD)

- **Role:** Clamp transients on CEC entering from HDMI cable.

## R1 — CEC pull-up

- **Role:** HDMI CEC bus is open-collector with pull-up. Some designs rely on TV-side pull-up only; if the node only listens, you may omit **local** pull-up—verify with scope. Many DIY ESP32 CEC adapters use **MCU internal pull-up + series resistor** or external 27k per HDMI 1.4b guidance.

## LED1 / R4 — Status

- **Role:** Blink on Wi‑Fi / WebSocket activity (firmware-defined).

## SW1 — User / boot

- **Role:** Force provisioning mode or factory reset (firmware policy).

---

See also [CEC_NOTES.md](CEC_NOTES.md) and KiCad nets in `hardware/kicad/tv-stretch-node/`.

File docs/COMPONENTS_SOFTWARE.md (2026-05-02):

# Software stack and components

## Firmware (ESP-IDF)

| Component | Version | Purpose |
|---|---|---|
| ESP-IDF | 5.2+ | Toolchain, FreeRTOS, Wi‑Fi, NVS, WebSocket client |
| `esp_websocket_client` | IDF built-in | Device ↔ server WebSocket |
| `cJSON` | IDF component | Parse/emit JSON commands |
| `nvs_flash` | IDF | Store WiFi SSID, API key, server URL, room id |

Optional later: `esp_http_client` for OTA, `mqtt_client` if moving to MQTT.

## Server (Python)

| Package | Version (constraint) | Purpose |
|---|---|---|
| Python | 3.12+ | Runtime |
| fastapi | ≥0.115 | HTTP + WebSocket API (devices + app presence) |
| uvicorn[standard] | ≥0.30 | ASGI server |
| sqlmodel | ≥0.0.22 | ORM + Pydantic models on SQLite |
| sqlalchemy | 2.x (via sqlmodel) | `EventLog` ordering, diagnostics |
| pydantic | ≥2 | Settings and validation |
| pydantic-settings | ≥2 | `TV_STRETCH_*` env config (`cors_origins`, `api_version`, …) |
| httpx | ≥0.27 | Tests / optional HTTP client |

Dev:

| Package | Purpose |
|---|---|
| pytest | Tests |
| pytest-asyncio | Async tests |
| ruff | Lint (optional) |

## Infrastructure

| Service | Purpose |
|---|---|
| Docker / Compose | Local all-in-one |
| eclipse-mosquitto | Optional MQTT; not required for default path |

## Mechanical CAD generation

| Tool | Purpose |
|---|---|
| Python `build123d` | Parametric enclosure; `scripts/generate_enclosure_step.py` |

Install: `pip install build123d` (may require OpenCASCADE system libs; see script docstring).

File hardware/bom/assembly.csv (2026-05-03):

Name | Description | Part | Count | Unit | Notes
1 | ESP32-C3 module | ESP32-C3-WROOM-02-N4 | 1 | pcs | 4MB flash
2 | HDMI CEC buffer | SN74LVCEXP125 | 1 | pcs | 3.3V level shift
3 | USB-C connector | USB408-GRN01 | 1 | pcs | 1
4 | Ferrite bead | BLM18EG471 | 1 | pcs | 470 ohm
5 | Capacitor 10uF | GRM188R60J106 | 1 | pcs | 0805
6 | Capacitor 0.1uF | GRM155R71C104 | 2 | pcs | 0805
7 | Resistor 10K | CRCW080510K0 | 2 | pcs | 1%
8 | Resistor 0 | CRCW0805000Z | 4 | pcs | 0805
9 | LED 0603 | Red LED | 1 | pcs | 0603
10 | Module pin header | 2x4 1.27mm | 1 | pcs | 2x4
11 | M2 screw | M2x6mm | 4 | pcs | DIN 912
12 | Heat shrink | 20mm | 50 | mm | PET

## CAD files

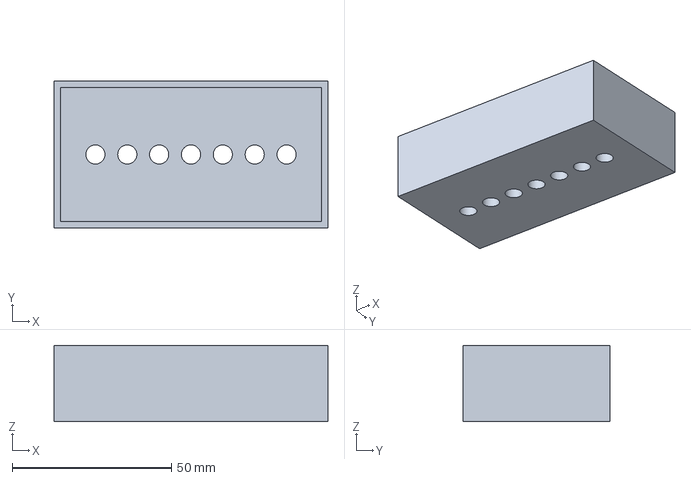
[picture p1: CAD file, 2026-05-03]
hardware/cad/enclosure/exports/ventilated_enclosure.step
86.0 x 46.0 x 24.0 mm

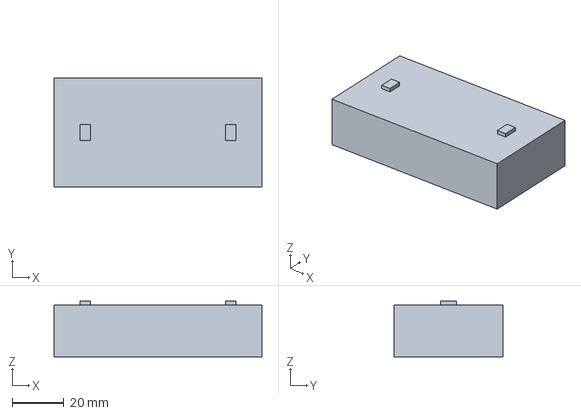
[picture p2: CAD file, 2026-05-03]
hardware/cad/enclosure/exports/snap_mount.step
80.0 x 42.0 x 21.5 mm

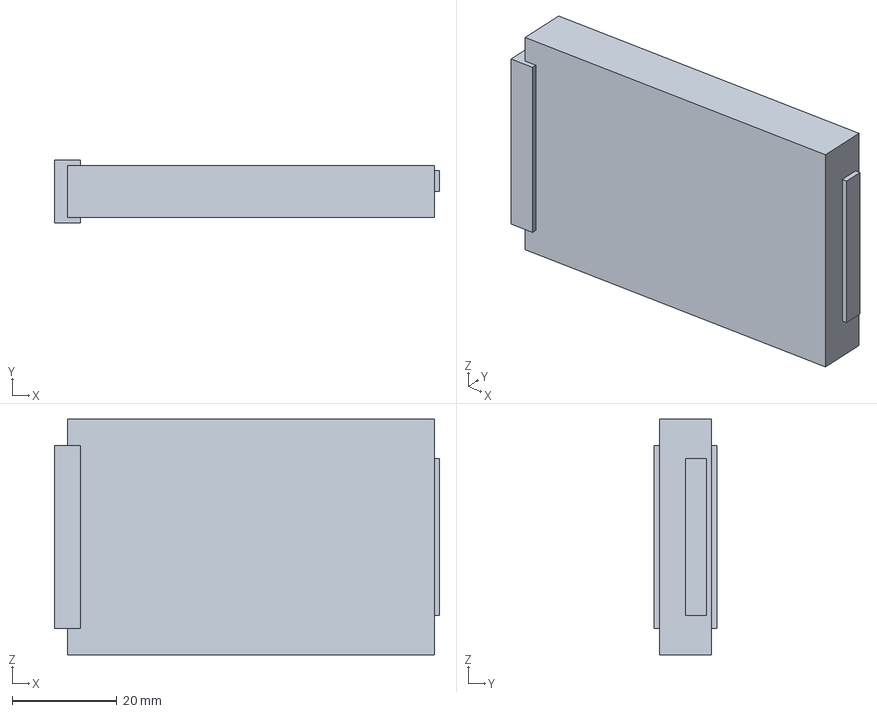
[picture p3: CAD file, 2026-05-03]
hardware/cad/enclosure/exports/din_rail_mount.step
73.5 x 12.0 x 45.0 mm

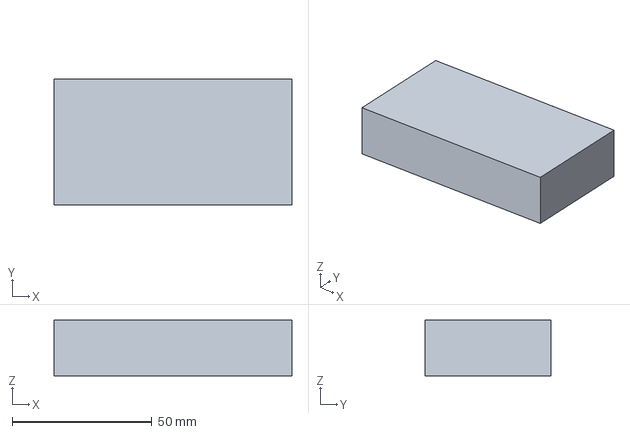
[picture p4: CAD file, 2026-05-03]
hardware/cad/enclosure/exports/plate_v2.step
85.0 x 45.0 x 20.0 mm

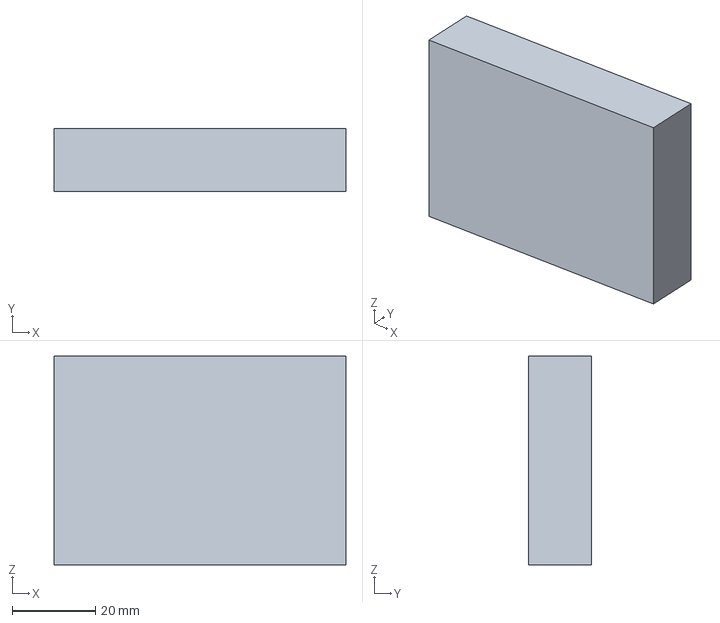
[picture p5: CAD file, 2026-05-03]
hardware/cad/enclosure/exports/magnetic_mount.step
70.0 x 15.0 x 50.0 mm

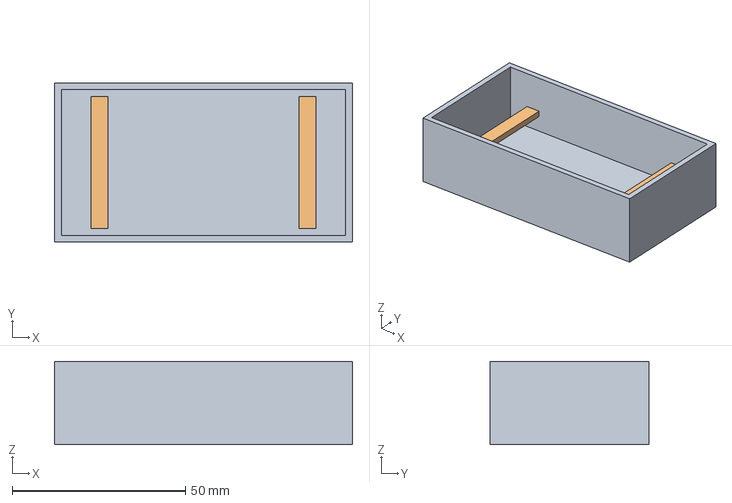
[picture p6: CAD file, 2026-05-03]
hardware/cad/enclosure/exports/stackable_case.step
86.0 x 46.0 x 24.0 mm

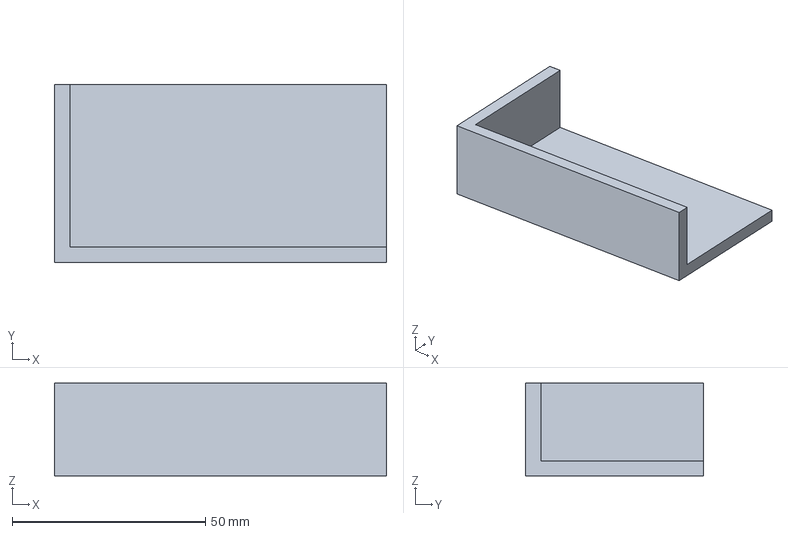
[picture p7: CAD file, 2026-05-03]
hardware/cad/enclosure/exports/enclosure.step
86.0 x 46.0 x 24.0 mm

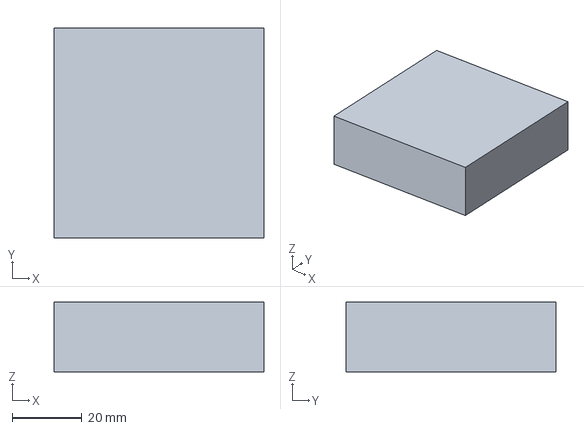
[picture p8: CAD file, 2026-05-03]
hardware/cad/enclosure/exports/corner_mount.step
60.0 x 60.0 x 20.0 mm

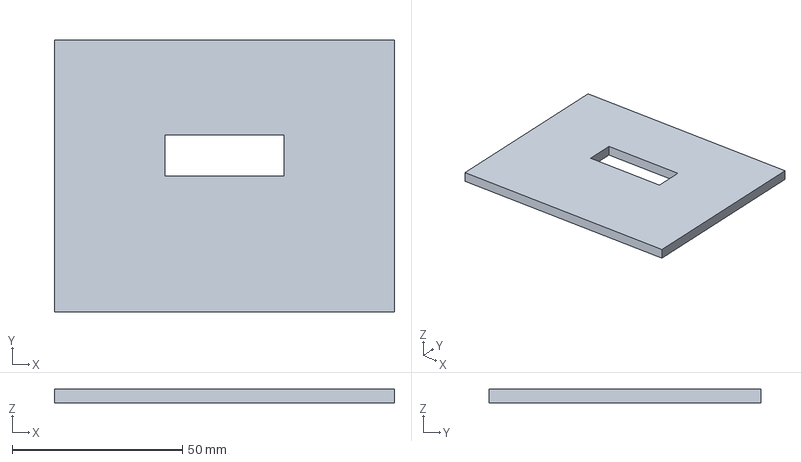
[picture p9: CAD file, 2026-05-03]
hardware/cad/enclosure/exports/vesa75_mount.step
100.0 x 80.0 x 4.00 mm

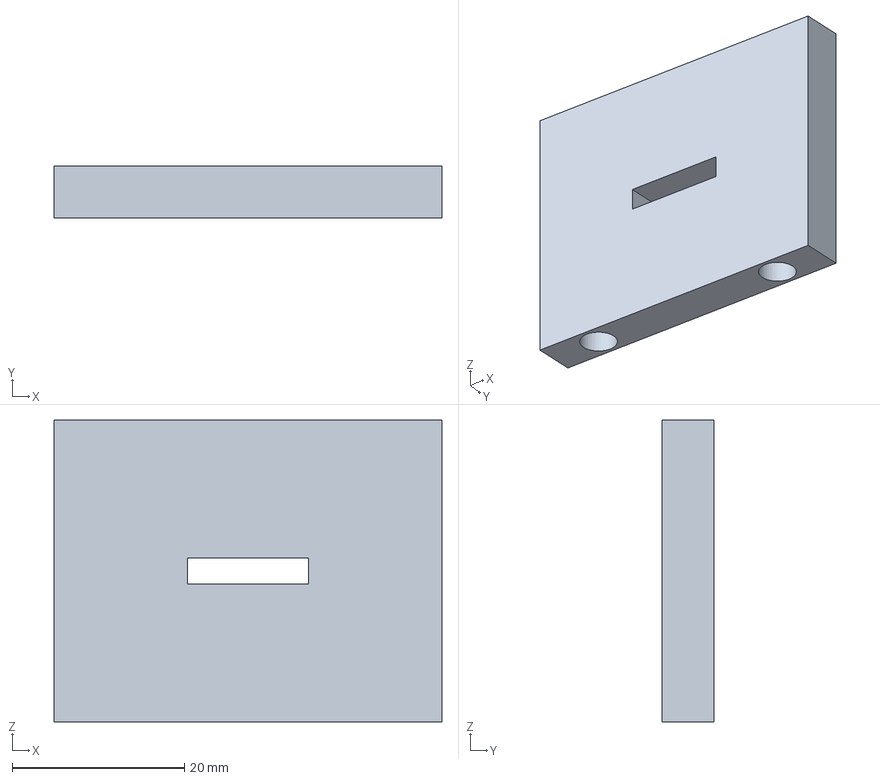
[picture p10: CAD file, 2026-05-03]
hardware/cad/enclosure/exports/hdmi_adapter.step
45.0 x 6.00 x 35.0 mm

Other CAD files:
hardware/cad/enclosure/exports/ribbon_clip.step
hardware/cad/enclosure/exports/back_plate.step
hardware/cad/enclosure/exports/uart_bracket.step
hardware/cad/enclosure/exports/enclosure_ip65.step
hardware/cad/enclosure/exports/antenna_mount.step
hardware/cad/enclosure/exports/led_cover.step
hardware/cad/enclosure/exports/pole_clamp.step
hardware/cad/enclosure/exports/sensor_housing.step
hardware/cad/enclosure/exports/adhesive_mount.step
hardware/cad/enclosure/exports/cable_clip.step
hardware/cad/enclosure/exports/compact_enclosure.step
hardware/cad/enclosure/exports/rackmount_small.step
hardware/cad/enclosure/exports/reset_button.step
hardware/cad/enclosure/exports/snap_in_holder.step
hardware/cad/enclosure/exports/tv_mount.step
hardware/cad/enclosure/exports/under_desk_mount.step
hardware/cad/enclosure/exports/usb_holder.step
hardware/cad/enclosure/exports/wall_bracket.step

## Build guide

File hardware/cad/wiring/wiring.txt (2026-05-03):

TV-STRETCH WIRING DIAGRAM
=========================

USB-C J1:
---------
Pin1  VBUS      → +5V (from TV or adapter)
Pin2  D-        → NC
Pin3  D+        → NC
Pin4  GND       → GND
Pin5  CC1       → 10K to GND (for 5V adapter)
Pin6  CC2       → NC
Pin7  SBU1      → NC
Pin8  SBU2      → NC

HDMI J2:
--------
Pin1   TMDS_D2+  → CEC (via 1K series)
Pin2   TMDS_D2GND → GND
Pin3   TMDS_D2-  → NC
Pin4   TMDS_D1+  → NC
Pin5   TMDS_D1GND→ GND
Pin6   TMDS_D1-  → NC
Pin7   TMDS_D0+  → NC
Pin8   TMDS_D0GND→ GND
Pin9   TMDS_D0-  → NC
Pin10  TMDS_CLK+  → NC
Pin11  TMDS_CLKGND→ GND
Pin12  TMDS_CLK- → NC
Pin13  CEC      → 1K series → Pin1 CEC+
Pin14  NC        → NC
Pin15  SCL       → NC
Pin16  SDA       → NC
Pin17  GND       → GND
Pin18  +5V       → NC (hot plug detect)

ESP32-C3:
---------
GPIO0   → LED (via 330R)
GPIO1   → CEC TX (via level shift)
GPIO2   → NC
GPIO3   → NC
GPIO4   → NC
GPIO5   → NC
GPIO6   → NC
GPIO7   → NC
GPIO8   → NC
GPIO9   → NC
GPIO10  → NC
GPIO11  → NC

POWER:
-------
5V USB → AMS1117-3.3 → 3.3V ESP32

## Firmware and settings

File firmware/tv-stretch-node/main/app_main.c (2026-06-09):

#include "cec/cec_bitbang.h"
#include "cec/cec_proto.h"
#include "cec/cec_rx.h"
#include "core/tvs_cmd_queue.h"
#include "core/tvs_state.h"
#include "driver/gpio.h"
#include "esp_event.h"
#include "esp_log.h"
#include "esp_netif.h"
#include "freertos/FreeRTOS.h"
#include "freertos/task.h"
#include "nvs.h"
#include "nvs_flash.h"
#include "net/tvs_wifi.h"
#include "net/ws_client.h"
#include "ota/tvs_ota.h"
#include "prov/prov_http.h"
#include "prov/tvs_nvs.h"
#include "proto/tv_stretch_proto.h"
#include "sdkconfig.h"
#include "sys/tvs_health.h"
#include "sys/tvs_led.h"
#include "sys/tvs_watchdog.h"
#include <cJSON.h>
#include <stdio.h>
#include <stdlib.h>
#include <string.h>

static const char *TAG = "tvs_main";

static char s_room_id[48];
static char s_home_id[48];

static void scpy(char *d, const char *s, size_t n)
{
    if (n == 0) return;
    strncpy(d, s, n - 1);
    d[n - 1] = 0;
}

static void nvs_get_str_d(nvs_handle_t h, const char *key, char *out, size_t out_sz,
                           const char *def)
{
    size_t len = out_sz;
    esp_err_t e = nvs_get_str(h, key, out, &len);
    if (e != ESP_OK && def) {
        scpy(out, def, out_sz);
    }
}

static int payload_int(cJSON *payload, const char *key, int fallback)
{
    if (!payload || !key) return fallback;
    cJSON *it = cJSON_GetObjectItem(payload, key);
    if (!it) return fallback;
    if (cJSON_IsNumber(it)) return (int)it->valuedouble;
    return fallback;
}

typedef struct {
    int mode;
    char s[300];
    bool only_diff;
} ota_job_t;

static void ota_task(void *p)
{
    ota_job_t *j = (ota_job_t *)p;
    tvs_led_set_pattern(TVS_LED_PATTERN_OTA);
    tvs_health_inc_ota_attempt();
    esp_err_t ret;
    if (j->mode == 0) {
        ret = tvs_ota_apply_from_url(j->s);
    } else {
        ret = tvs_ota_apply_from_manifest_url(j->s, j->only_diff);
    }
    if (ret == ESP_OK) {
        tvs_health_inc_ota_success();
    }
    free(j);
    tvs_led_set_pattern(TVS_LED_PATTERN_CONNECTED);
    vTaskDelete(NULL);
}

#if CONFIG_TVS_OTA_AUTO_CHECK_ON_BOOT
static void boot_ota_task(void *arg)
{
    (void)arg;
    vTaskDelay(pdMS_TO_TICKS(5000));
    if (CONFIG_TVS_OTA_BOOT_MANIFEST_URL[0] != '\0') {
        ESP_LOGI(TAG, "Boot OTA check: %s", CONFIG_TVS_OTA_BOOT_MANIFEST_URL);
        tvs_led_set_pattern(TVS_LED_PATTERN_OTA);
        tvs_health_inc_ota_attempt();
        esp_err_t ret = tvs_ota_apply_from_manifest_url(CONFIG_TVS_OTA_BOOT_MANIFEST_URL, true);
        if (ret == ESP_OK) {
            tvs_health_inc_ota_success();
        }
    }
    tvs_led_set_pattern(TVS_LED_PATTERN_CONNECTING);
    vTaskDelete(NULL);
}
#endif

static void handle_command(const char *cmd, const cJSON *payload)
{
    if (!cmd) return;

    if (strcmp(cmd, "noop") == 0) {
        ESP_LOGD(TAG, "noop");
        return;
    }
    if (strcmp(cmd, "policy") == 0) {
        ESP_LOGI(TAG, "policy (see server)");
        (void)payload;
        return;
    }
    if (strcmp(cmd, "ota_pull") == 0 && payload) {
        cJSON *url = cJSON_GetObjectItem((cJSON *)payload, "url");
        cJSON *murl = cJSON_GetObjectItem((cJSON *)payload, "manifest_url");
        if (cJSON_IsString(url) && url->valuestring) {
            ota_job_t *j = (ota_job_t *)calloc(1, sizeof(ota_job_t));
            if (!j) return;
            j->mode = 0;
            scpy(j->s, url->valuestring, sizeof(j->s));
            xTaskCreate(ota_task, "ota", 10240, j, 5, NULL);
            return;
        }
        if (cJSON_IsString(murl) && murl->valuestring) {
            ota_job_t *j = (ota_job_t *)calloc(1, sizeof(ota_job_t));
            if (!j) return;
            j->mode = 1;
            j->only_diff = true;
            cJSON *od = cJSON_GetObjectItem((cJSON *)payload, "only_if_version_differs");
            if (cJSON_IsBool(od)) j->only_diff = cJSON_IsTrue(od);
            scpy(j->s, murl->valuestring, sizeof(j->s));
            xTaskCreate(ota_task, "ota", 10240, j, 5, NULL);
            return;
        }
        return;
    }
    if (strcmp(cmd, "cec_broadcast_ping") == 0) {
        uint8_t ping = CEC_OP_GIVE_PHYSICAL_ADDR;
        tvs_cec_send_frame(CEC_ADDR_BROADCAST, CEC_ADDR_BROADCAST, &ping, 1);
        tvs_health_inc_cec_tx();
        return;
    }
    if (strcmp(cmd, "cec_standby") == 0) {
        int initiator = payload_int((cJSON *)payload, "initiator", CONFIG_TVS_CEC_LOGICAL_ADDR);
        int destination = payload_int((cJSON *)payload, "destination", CEC_ADDR_TV);
        uint8_t op = CEC_OP_STANDBY;
        tvs_cec_send_frame(initiator & 0x0F, destination & 0x0F, &op, 1);
        tvs_health_inc_cec_tx();
        return;
    }
    if (strcmp(cmd, "cec_active_source") == 0 && payload) {
        int addr = payload_int((cJSON *)payload, "physical_address", CONFIG_TVS_CEC_PHYSICAL_ADDR);
        uint8_t body[3] = {CEC_OP_ACTIVE_SOURCE, (uint8_t)((addr >> 8) & 0xFF), (uint8_t)(addr & 0xFF)};
        tvs_cec_send_frame(CONFIG_TVS_CEC_LOGICAL_ADDR, CEC_ADDR_BROADCAST, body, sizeof(body));
        tvs_health_inc_cec_tx();
        return;
    }
    if (strcmp(cmd, "cec_user_control") == 0 && payload) {
        int key = payload_int((cJSON *)payload, "key", 0);
        uint8_t body[2] = {CEC_OP_USER_CONTROL_PRESSED, (uint8_t)(key & 0xFF)};
        int initiator = payload_int((cJSON *)payload, "initiator", CONFIG_TVS_CEC_LOGICAL_ADDR);
        int destination = payload_int((cJSON *)payload, "destination", CEC_ADDR_TV);
        tvs_cec_send_frame(initiator & 0x0F, destination & 0x0F, body, sizeof(body));
        tvs_health_inc_cec_tx();
        return;
    }
    if (strcmp(cmd, "cec_set_stream_path") == 0 && payload) {
        int addr = payload_int((cJSON *)payload, "physical_address", CONFIG_TVS_CEC_PHYSICAL_ADDR);
        uint8_t body[3] = {CEC_OP_SET_STREAM_PATH, (uint8_t)((addr >> 8) & 0xFF), (uint8_t)(addr & 0xFF)};
        tvs_cec_send_frame(CEC_ADDR_TV, CEC_ADDR_BROADCAST, body, sizeof(body));
        tvs_health_inc_cec_tx();
        return;
    }
    if (strcmp(cmd, "cec_send_raw") == 0 && payload && cJSON_IsArray(payload)) {
        int n = cJSON_GetArraySize(payload);
        if (n <= 0 || n > CEC_MAX_FRAME_BYTES) return;
        uint8_t buf[CEC_MAX_FRAME_BYTES];
        for (int i = 0; i < n; i++) {
            cJSON *it = cJSON_GetArrayItem(payload, i);
            if (!cJSON_IsNumber(it)) return;
            buf[i] = (uint8_t)it->valueint;
        }
        uint8_t initiator = (buf[0] >> 4) & 0x0F;
        uint8_t dest = buf[0] & 0x0F;
        tvs_cec_send_frame(initiator, dest, buf + 1, (size_t)(n - 1));
        tvs_health_inc_cec_tx();
        return;
    }
    if (strcmp(cmd, "scan_bus") == 0) {
        tvs_cec_proto_scan_bus();
        return;
    }
    if (strcmp(cmd, "health_report") == 0) {
        char hjson[512];
        tvs_health_build_json(hjson, sizeof(hjson));
        tvs_ws_send_text(hjson);
        return;
    }
    if (strcmp(cmd, "reset_health") == 0) {
        tvs_health_reset();
        return;
    }
    ESP_LOGW(TAG, "unknown cmd %s", cmd);
}

static void cmd_complete_cb(const char *batch_id, const char *cmd, bool ok)
{
    if (ok) {
        tvs_health_inc_ack();
    } else {
        tvs_health_inc_nack();
    }
}

static void on_cec_frame(uint8_t initiator, uint8_t destination,
                          const uint8_t *body, uint8_t body_len)
{
    tvs_health_inc_cec_rx();
    tvs_cec_proto_process_frame(initiator, destination, body, body_len);
}

static void process_cmd_queue(void)
{
    tvs_cmd_entry_t entry;
    while (tvs_cmd_dequeue(&entry)) {
        cJSON *payload = NULL;
        if (entry.payload_json[0] != '\0') {
            payload = cJSON_Parse(entry.payload_json);
        }
        handle_command(entry.cmd, payload);
        if (payload) cJSON_Delete(payload);
        tvs_cmd_ack(entry.batch_id, entry.cmd);
    }
    tvs_health_set_cmd_depth(tvs_cmd_queue_depth());
}

static void on_ws_message(const char *json, void *ctx)
{
    (void)ctx;
    cJSON *root = cJSON_Parse(json);
    if (!root) {
        ESP_LOGW(TAG, "JSON parse fail");
        return;
    }
    cJSON *v = cJSON_GetObjectItem(root, "v");
    cJSON *type = cJSON_GetObjectItem(root, "type");
    if (!cJSON_IsNumber(v) || (int)v->valuedouble != TVS_PROTO_VER || !cJSON_IsString(type)) {
        cJSON_Delete(root);
        return;
    }

    if (strcmp(type->valuestring, "command_batch") == 0) {
        cJSON *cmds = cJSON_GetObjectItem(root, "commands");
        cJSON *bid = cJSON_GetObjectItem(root, "batch_id");
        const char *bs = cJSON_IsString(bid) ? bid->valuestring : "";

        if (cJSON_IsArray(cmds)) {
            int n = cJSON_GetArraySize(cmds);
            for (int i = 0; i < n; i++) {
                cJSON *c = cJSON_GetArrayItem(cmds, i);
                cJSON *cmd = cJSON_GetObjectItem(c, "cmd");
                cJSON *payload = cJSON_GetObjectItem(c, "payload");

                if (cJSON_IsString(cmd)) {
                    char *payload_str = payload ? cJSON_PrintUnformatted(payload) : NULL;
                    tvs_cmd_enqueue(bs, cmd->valuestring, payload_str);
                    if (payload_str) free(payload_str);
                }
            }
        }

        tvs_led_pulse();
        char ack[192];
        snprintf(ack, sizeof(ack), "{\"v\":1,\"type\":\"ack\",\"batch_id\":\"%s\",\"ok\":true}", bs);
        tvs_ws_send_text(ack);
    }
    cJSON_Delete(root);
}

static void on_ws_connect(bool connected, void *ctx)
{
    (void)ctx;
    if (connected) {
        tvs_state_transition(TVS_STATE_WS_CONNECTED);
        vTaskDelay(pdMS_TO_TICKS(200));
        char hello[512];
        snprintf(hello, sizeof(hello),
                 "{\"v\":1,\"type\":\"hello\",\"node\":{\"room_id\":\"%s\",\"home_id\":\"%s\",\"fw\":\"%s\"}}",
                 s_room_id, s_home_id, CONFIG_TVS_FW_VERSION);
        tvs_ws_send_text(hello);

        tvs_health_reset();
        tvs_cec_rx_reset_counts();
    } else {
        tvs_health_inc_ws_reconnect();
        tvs_state_transition(TVS_STATE_DISCONNECTED);
    }
}

static void on_state_change(tvs_state_t old_state, tvs_state_t new_state)
{
    (void)old_state;
    switch (new_state) {
    case TVS_STATE_COLD_START:
    case TVS_STATE_PROVISIONING:
        tvs_led_set_pattern(TVS_LED_PATTERN_BOOT);
        break;
    case TVS_STATE_WIFI_CONNECT:
    case TVS_STATE_WIFI_WAIT:
    case TVS_STATE_WS_CONNECT:
        tvs_led_set_pattern(TVS_LED_PATTERN_CONNECTING);
        break;
    case TVS_STATE_WS_CONNECTED:
        tvs_led_set_pattern(TVS_LED_PATTERN_CONNECTED);
        break;
    case TVS_STATE_DISCONNECTED:
        tvs_led_set_pattern(TVS_LED_PATTERN_CONNECTING);
        break;
    case TVS_STATE_ERROR:
        tvs_led_set_pattern(TVS_LED_PATTERN_ERROR);
        break;
    case TVS_STATE_DEEP_SLEEP:
        tvs_led_set_pattern(TVS_LED_PATTERN_OFF);
        break;
    default:
        break;
    }
}

static void heartbeat_task(void *arg)
{
    (void)arg;
    while (1) {
        vTaskDelay(pdMS_TO_TICKS(25000));
        if (tvs_state_is_connected()) {
            const char *hb = "{\"v\":1,\"type\":\"heartbeat\"}";
            tvs_ws_send_text(hb);
        }
    }
}

static void health_task(void *arg)
{
    (void)arg;
    while (1) {
        vTaskDelay(pdMS_TO_TICKS(CONFIG_TVS_HEALTH_INTERVAL * 1000));
        tvs_health_t h;
        tvs_health_collect(&h);

        ESP_LOGI(TAG, "health: up=%us rssi=%d cec_tx=%lu cec_rx=%lu cec_err=%lu "
                 "ws_recon=%lu heap=%lu/%lu cmdq=%lu ota=%lu/%lu acks=%lu/%lu",
                 (unsigned)h.uptime_sec, h.wifi_rssi,
                 (unsigned long)h.cec_tx_frames, (unsigned long)h.cec_rx_frames,
                 (unsigned long)h.cec_rx_errors,
                 (unsigned long)h.ws_reconnects,
                 (unsigned long)h.free_heap, (unsigned long)h.min_free_heap,
                 (unsigned long)h.cmd_queue_depth,
                 (unsigned long)h.ota_attempts, (unsigned long)h.ota_successes,
                 (unsigned long)h.ack_count, (unsigned long)h.nack_count);

        if (tvs_state_is_connected()) {
            char hjson[512];
            tvs_health_build_json(hjson, sizeof(hjson));
            tvs_ws_send_text(hjson);
        }
    }
}

static void cmd_queue_task(void *arg)
{
    (void)arg;
    while (1) {
        process_cmd_queue();
        vTaskDelay(pdMS_TO_TICKS(50));
    }
}

static void wifi_event_handler(void *arg, esp_event_base_t base,
                                int32_t id, void *data)
{
    (void)arg;
    (void)data;
    if (base == WIFI_EVENT && id == WIFI_EVENT_STA_DISCONNECTED) {
        ESP_LOGW(TAG, "WiFi disconnected");
        tvs_state_transition(TVS_STATE_WIFI_CONNECT);
    }
}

void app_main(void)
{
    ESP_ERROR_CHECK(nvs_flash_init());

    tvs_led_init((gpio_num_t)CONFIG_TVS_STATUS_LED_GPIO);
    tvs_led_set_pattern(TVS_LED_PATTERN_BOOT);

    tvs_watchdog_init(CONFIG_TVS_WATCHDOG_TIMEOUT);

    tvs_state_init(on_state_change);
    tvs_state_transition(TVS_STATE_COLD_START);

    ESP_ERROR_CHECK(tvs_cec_init((gpio_num_t)CONFIG_TVS_CEC_GPIO));
    ESP_ERROR_CHECK(tvs_cec_rx_init((gpio_num_t)CONFIG_TVS_CEC_GPIO));
    tvs_cec_rx_set_callback(on_cec_frame);

    tvs_cec_proto_init(NULL);
    tvs_cmd_queue_init(cmd_complete_cb);
    tvs_health_init();

    ESP_ERROR_CHECK(esp_netif_init());
    ESP_ERROR_CHECK(esp_event_loop_create_default());
    ESP_ERROR_CHECK(esp_event_handler_register(WIFI_EVENT, WIFI_EVENT_STA_DISCONNECTED,
                                                wifi_event_handler, NULL));

#if CONFIG_TVS_HTTP_PROVISIONING
    if (!tvs_nvs_is_provisioned()) {
        ESP_LOGW(TAG, "NVS not provisioned -- setup SoftAP");
        tvs_state_transition(TVS_STATE_PROVISIONING);
        tvs_prov_run_http_setup();
    }
#endif

    nvs_handle_t nvs;
    ESP_ERROR_CHECK(nvs_open("tvstretch", NVS_READONLY, &nvs));

    char ssid[64] = {0};
    char pass[64] = {0};
    char ws_url[160] = {0};
    char api_key[96] = {0};

    nvs_get_str_d(nvs, "wifi_ssid", ssid, sizeof(ssid), CONFIG_TVS_WIFI_SSID);
    nvs_get_str_d(nvs, "wifi_pass", pass, sizeof(pass), CONFIG_TVS_WIFI_PASSWORD);
    nvs_get_str_d(nvs, "ws_url", ws_url, sizeof(ws_url), CONFIG_TVS_SERVER_WS_URL);
    nvs_get_str_d(nvs, "api_key", api_key, sizeof(api_key), CONFIG_TVS_NODE_API_KEY);
    nvs_get_str_d(nvs, "room_id", s_room_id, sizeof(s_room_id), CONFIG_TVS_ROOM_ID);
    nvs_get_str_d(nvs, "home_id", s_home_id, sizeof(s_home_id), CONFIG_TVS_HOME_ID);
    nvs_close(nvs);

    esp_netif_create_default_wifi_sta();
    tvs_state_transition(TVS_STATE_WIFI_CONNECT);
    ESP_ERROR_CHECK(tvs_wifi_start_sta(ssid, pass));

#if CONFIG_TVS_CEC_RX_ENABLE
    tvs_cec_rx_start();
    ESP_LOGI(TAG, "CEC RX enabled");
#endif

    xTaskCreate(cmd_queue_task, "cmdq", 4096, NULL, 6, NULL);

#if CONFIG_TVS_OTA_AUTO_CHECK_ON_BOOT
    if (CONFIG_TVS_OTA_BOOT_MANIFEST_URL[0] != '\0') {
        xTaskCreate(boot_ota_task, "boot_ota", 8192, NULL, 3, NULL);
    }
#endif

    tvs_ws_start(ws_url, api_key, s_home_id, s_room_id,
                 on_ws_message, on_ws_connect, NULL);
    tvs_state_transition(TVS_STATE_WS_CONNECT);

    xTaskCreate(heartbeat_task, "hb", 3072, NULL, 5, NULL);
    xTaskCreate(health_task, "health", 3072, NULL, 2, NULL);

    while (1) {
        tvs_watchdog_feed();
        vTaskDelay(pdMS_TO_TICKS(5000));
    }
}

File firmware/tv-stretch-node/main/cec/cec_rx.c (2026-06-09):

#include "cec/cec_rx.h"
#include "esp_log.h"
#include "esp_timer.h"
#include "freertos/FreeRTOS.h"
#include "freertos/task.h"
#include <string.h>

static const char *TAG = "tvs_cec_rx";

static gpio_num_t s_rx_pin = GPIO_NUM_NC;
static tvs_cec_rx_cb s_rx_cb = NULL;
static volatile bool s_rx_active = false;
static volatile bool s_tx_active = false;
static volatile uint32_t s_frame_count = 0;
static volatile uint32_t s_error_count = 0;

static cec_edge_t s_ring[CEC_RX_RING_SIZE];
static volatile uint32_t s_ring_head = 0;
static volatile uint32_t s_ring_tail = 0;

static TaskHandle_t s_decode_task = NULL;

#define IN_RANGE(min, max, val)  ((val) >= (min) && (val) <= (max))

#define START_BIT_LOW_MIN  3000
#define START_BIT_LOW_MAX  4500
#define START_BIT_HIGH_MIN  400
#define START_BIT_HIGH_MAX 1200

#define BIT_0_LOW_MIN  1000
#define BIT_0_LOW_MAX  2000
#define BIT_0_HIGH_MIN  400
#define BIT_0_HIGH_MAX 1400

#define BIT_1_LOW_MIN   350
#define BIT_1_LOW_MAX   950
#define BIT_1_HIGH_MIN  350
#define BIT_1_HIGH_MAX  950

#define ACK_LOW_MIN  600
#define ACK_LOW_MAX 2000

#define FRAME_IDLE_TIMEOUT_US 5000
#define DEBOUNCE_SKIP_US 20

static bool ring_push(int64_t ts, uint8_t level)
{
    uint32_t next = (s_ring_head + 1) % CEC_RX_RING_SIZE;
    if (next == s_ring_tail) {
        return false;
    }
    s_ring[s_ring_head].timestamp_us = ts;
    s_ring[s_ring_head].level = level;
    s_ring_head = next;
    return true;
}

static bool ring_pop(int64_t *ts, uint8_t *level)
{
    if (s_ring_tail == s_ring_head) {
        return false;
    }
    *ts = s_ring[s_ring_tail].timestamp_us;
    *level = s_ring[s_ring_tail].level;
    s_ring_tail = (s_ring_tail + 1) % CEC_RX_RING_SIZE;
    return true;
}

static void IRAM_ATTR cec_isr_handler(void *arg)
{
    (void)arg;
    if (s_tx_active) {
        return;
    }
    int64_t now = esp_timer_get_time();
    uint8_t level = (uint8_t)gpio_get_level(s_rx_pin);
    ring_push(now, level);
}

static int decode_bit(int64_t low_us, int64_t high_us)
{
    if (IN_RANGE(START_BIT_LOW_MIN, START_BIT_LOW_MAX, low_us) &&
        IN_RANGE(START_BIT_HIGH_MIN, START_BIT_HIGH_MAX, high_us)) {
        return 2;
    }
    if (IN_RANGE(BIT_0_LOW_MIN, BIT_0_LOW_MAX, low_us) &&
        IN_RANGE(BIT_0_HIGH_MIN, BIT_0_HIGH_MAX, high_us)) {
        return 0;
    }
    if (IN_RANGE(BIT_1_LOW_MIN, BIT_1_LOW_MAX, low_us) &&
        IN_RANGE(BIT_1_HIGH_MIN, BIT_1_HIGH_MAX, high_us)) {
        return 1;
    }
    return -1;
}

static void dispatch_frame(const uint8_t *buf, uint8_t len)
{
    if (len < 1 || !s_rx_cb || s_tx_active) {
        return;
    }
    uint8_t header = buf[0];
    uint8_t initiator = (header >> 4) & 0x0F;
    uint8_t dest = header & 0x0F;
    s_rx_cb(initiator, dest, len > 1 ? &buf[1] : NULL, len > 1 ? len - 1 : 0);
    s_frame_count++;
}

static void decode_frame_task(void *arg)
{
    (void)arg;
    int64_t prev_ts = 0;
    uint8_t prev_level = 0;

    bool in_frame = false;
    int64_t low_stored = 0;
    bool have_low = false;
    bool start_bit_seen = false;

    uint8_t frame_buf[CEC_RX_FRAME_MAX];
    uint8_t frame_len = 0;
    uint8_t current_byte = 0;
    uint8_t bits_collected = 0;
    bool eom = false;

    while (1) {
        int64_t ts;
        uint8_t level;
        while (ring_pop(&ts, &level)) {
            if (level == prev_level) {
                continue;
            }
            if (ts - prev_ts < DEBOUNCE_SKIP_US) {
                continue;
            }

            if (level == 1) {
                int64_t low_us = ts - prev_ts;

                if (!in_frame) {
                    if (IN_RANGE(START_BIT_LOW_MIN, START_BIT_LOW_MAX, low_us)) {
                        in_frame = true;
                        start_bit_seen = true;
                        have_low = false;
                        frame_len = 0;
                        current_byte = 0;
                        bits_collected = 0;
                        eom = false;
                    }
                } else {
                    if (start_bit_seen) {
                        start_bit_seen = false;
                        have_low = false;
                    } else {
                        low_stored = low_us;
                        have_low = true;
                    }
                }
                prev_ts = ts;
                prev_level = level;
                continue;
            }

            if (level == 0) {
                int64_t high_us = ts - prev_ts;

                if (!in_frame) {
                    prev_ts = ts;
                    prev_level = level;
                    continue;
                }

                if (start_bit_seen) {
                    if (!IN_RANGE(START_BIT_HIGH_MIN, START_BIT_HIGH_MAX, high_us)) {
                        s_error_count++;
                        in_frame = false;
                    }
                    start_bit_seen = false;
                    have_low = false;
                    prev_ts = ts;
                    prev_level = level;
                    continue;
                }

                if (!have_low) {
                    s_error_count++;
                    in_frame = false;
                    prev_ts = ts;
                    prev_level = level;
                    continue;
                }

                int bit = decode_bit(low_stored, high_us);
                have_low = false;

                if (bit == 2) {
                    if (frame_len > 0) {
                        ESP_LOGD(TAG, "frame aborted by new start, len=%d", frame_len);
                    }
                    in_frame = true;
                    start_bit_seen = true;
                    frame_len = 0;
                    current_byte = 0;
                    bits_collected = 0;
                    eom = false;
                    prev_ts = ts;
                    prev_level = level;
                    continue;
                }

                if (bit < 0) {
                    if (bits_collected == 9 &&
                        IN_RANGE(ACK_LOW_MIN, ACK_LOW_MAX, low_stored)) {
                        if (frame_len < CEC_RX_FRAME_MAX) {
                            frame_buf[frame_len++] = current_byte;
                        }
                        current_byte = 0;
                        bits_collected = 0;
                        if (eom) {
                            dispatch_frame(frame_buf, frame_len);
                            in_frame = false;
                        }
                        prev_ts = ts;
                        prev_level = level;
                        continue;
                    }
                    s_error_count++;
                    in_frame = false;
                    prev_ts = ts;
                    prev_level = level;
                    continue;
                }
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

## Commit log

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2026-05-02 KiCad: add schematic
    [tv-stretch-node.kicad_sch]
2026-05-02 KiCad: add PCB layout and export notes
    [tv-stretch-node.kicad_pcb]
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2026-05-02 CAD: export enclosure STEP for manufacturing
    [enclosure.step]
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2026-05-02 Firmware: configure partition table and default sdkconfig
    [partitions.csv]
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2026-05-02 feat(server): complete WebSocket protocols and handoff policy
    - Device /ws/device: query auth (?home_id=&token=) for browser testing; handle
    heartbeat (last_seen) and event (EventLog device_event)
    - App /ws/app: presence standby_others optional; get_session reply
    - REST POST /sessions/handoff: standby_others body field (default true)
2026-05-02 feat(ui): device simulator and standby controls
    - Panel for /ws/device with query auth, auto-ack batches, hello/heartbeat
    - Register node from selected room; REST/UI standby_others toggles
    - App WS get_session button; dual badges for app vs device channels
2026-05-02 refactor(ui): split control panel into CSS and ES modules
    - index.html ~157 lines: markup + /ui/css/app.css + type=module main.js
    - js/: dom, logger, context, badges, ws-urls, storage, rest, ws-app, ws-device
    - Absolute /ui/... asset URLs so scripts load under any /ui path
2026-05-02 feat(ui): deck out control lab — nav, diagnostics, export, v0.5.0
    - Sticky section nav, anchor targets, theme-color and favicon SVG
    - Version chip + footer hint from /health/ready; diagnostics overview + live WS snapshot
    - Log download button and Ctrl/Cmd+Shift+S; refined CSS (kbd, panels, a11y motion)
    - Bump package/API default version to 0.5.0
2026-05-02 feat(server): spatial maps, occupancy handoff, optical hardware docs
    Add SpatialMap storage and REST (/spatial/maps). POST /presence/occupancy
    mirrors sessions/handoff when confidence meets TV_STRETCH_PRESENCE_HANDOFF_MIN_CONFIDENCE.
    Lab UI: list/post maps and occupancy from browser. Docs: API, ARCHITECTURE,
    optional BOM for RGB-D/ToF rig; HARDWARE_OPTICAL_SLAM_STACK describes PCB→server flow.
    Tests reset SlowAPI limiter between runs; home delete cascades spatial maps.
    Bump package to 0.6.0.
2026-05-03 feat(server): add security headers middleware
    - X-Content-Type-Options: nosniff
    - X-Frame-Options: DENY
    - X-XSS-Protection: 1; mode=block
    - Referrer-Policy: strict-origin-when-cross-origin
    - Permissions-Policy: camera=(), microphone=(), geolocation=()
2026-05-03 feat(server): add OccupancyEvent model for SLAM tracking
    - Stores room_id, confidence, source, pose_x/y/yaw, map_id
    - Enables occupancy analytics and history
2026-05-03 feat(server): enhance presence API with occupancy tracking
    - Store OccupancyEvent on every occupancy report
    - Add /presence/occupancy/history endpoint
    - Add /presence/slam/update endpoint
    - Improve pose tracking (x_m, y_m, yaw_rad)
2026-05-03 cad(enclosure): add wall mount bracket
    Parametric wall mount for 80x60mm surface:
    - M4 screw holes at 50mm spacing
    - Hook tab for hanging
    - Print-in-place no supports
2026-05-03 cad(templates): add drill template and wiring doc
    - Mounting template (1:1 scale)
    - Assembly BOM CSV
    - Wiring pinout diagram
    [assembly.csv]
2026-05-03 cad(enclosure): add VESA and magnetic mount options
    - VESA 75/100 adapter plate
    - Magnetic mount with pocket
    - Cable clip organizer
2026-05-03 cad(enclosure): add stackable and ventilated cases
    - Stackable case with daisy-chain slots
    - Ventilated with fan-ready vents
2026-05-03 cad(enclosure): add snap and adhesive mount options
    - Press-fit snap mount
    - Adhesive tape pad mount
2026-05-03 cad: add wall bracket and HDMI adapter STEPs
    - wall_bracket.step (80x60mm wall mount)
    - hdmi_adapter.step (panel mount)
    - din_rail_mount.step (35mm DIN)
    - vesa75_mount.step (VESA 75/100)
    - magnetic_mount.step (magnet pocket)
    - cable_clip.step (cable organizer)
    - snap_mount.step (press-fit)
    - adhesive_mount.step (tape mount)
    - ventilated_enclosure.step (fan ready)
    - compact_enclosure.step (small case)
    - stackable_case.step (daisy-chain)
    [adhesive_mount.step, cable_clip.step, compact_enclosure.step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]
2026-05-03 cad: adhesive mount and cable clip
    [adhesive_mount.step, antenna_mount.step, back_plate.step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]
2026-05-03 cad: more mount variants and accessories
    - pole_clamp, rackmount_small
    - led_cover, reset_button
    - sensor_housing, snap_in_holder
    - uart_bracket, back_plate
    - plate_v2, enclosure_ip65
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2026-05-14 test: add tests for power control, CEC keys, input select, and statistics
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2026-06-09 feat: add MQTT event publishing service
    Integrates paho-mqtt to publish server events (occupancy, handoffs,
    power control, CEC keypresses, SLAM updates) to the local Mosquitto
    broker on structured topics under tvstretch/{home_id}/.
    MQTT is enabled by default (TV_STRETCH_MQTT_ENABLED=true) and
    gracefully handles broker unavailability.
2026-06-09 feat: implement AppHub for WebSocket event broadcasting
    Introduces AppHub (analogous to DeviceHub) that tracks app WebSocket
    connections per home. The subscribe_events message now adds the
    connection to a subscriber list; events (handoffs, occupancy, power,
    etc.) are broadcast in real-time to all subscribed app clients.
    The AppHub snapshot is also exposed in the diagnostics overview.
2026-06-09 feat: publish session events via MQTT and AppHub
    All session endpoints (handoff, power, cec-key, input-select) now
    publish structured events to MQTT and broadcast to subscribed app
    WebSocket clients in addition to the existing device WS push.
    The diagnostics overview now includes AppHub connection stats and
    MQTT broker connection status.
2026-06-09 feat: add firmware unit tests with Unity framework
    Adds ESP-IDF test component under main/test/ with Unity-based tests:
    - test_protocol: validates protocol constants, message type enum,
    and tvs_command_t struct layout
    - test_cec_frame: verifies CEC frame construction for Active Source
    opcode, physical address encoding, and standby/ping opcodes
    - test_nvs: verifies provisioned-state check behavior
    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
2026-06-09 docs: add comprehensive firmware architecture documentation
    Detailed document covering the ESP32-C3 node firmware:
    - System overview and boot sequence diagram
    - Module map with file locations and purposes
    - CEC driver design with timing details
    - WebSocket protocol message reference
    - Command dispatch table
    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
2026-06-09 feat: implement full firmware architecture with state machine, CEC RX, command queue, and system modules
    - Add core state machine (tvs_state) for lifecycle management
    - Add command queue (tvs_cmd_queue) with retry/ACK/NACK support
    - Add CEC RX (cec_rx) with GPIO interrupt edge capture and software decode
    - Add CEC protocol layer (cec_proto) for opcode parsing and bus scan
    - Add LED pattern engine (tvs_led) with per-state patterns
    - Add health telemetry (tvs_health) for uptime/RSSI/frame counters
    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
2026-06-09 fix: rewrite CEC RX decode, add CEC responders, LEDC PWM, health JSON, watchdog task API
    - CEC RX: fix decode using edge-pair approach (rising stores low, falling decodes with both low+high), add ACK timing recovery, debounce, frame timeout, error counting
    - CEC proto: add responders for GIVE_PHYSICAL_ADDR/GIVE_OSD_NAME/GIVE_DEVICE_POWER_STATUS/REQUEST_ACTIVE_SOURCE, improved bus scan with timing and device count
    - LED: rewrite with LEDC PWM 8-bit/5kHz, smooth fading, per-pattern brightness config
    - Health: add JSON builder for WS publishing, new counters (CEC errors, OTA, ACK/NACK), RSSI API
    - Watchdog: add task subscription API with per-task timeout, feed count, status query
    - Kconfig: add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
    [app_main.c, cec_rx.c, tvs_led.c]
2026-10-04 fix(server): use tz-aware cutoffs in statistics and occupancy queries (#1)
    datetime.now() produced naive datetimes that were compared against and bound
    to timezone-aware columns, which raises on current SQLModel/SQLAlchemy and made
    GET /homes/{id}/statistics, GET /rooms/{id}/statistics,
    GET /presence/occupancy/aggregate and DELETE /presence/occupancy/history fail.
    Switch those cutoffs to the shared utcnow() helper and cover the previously
    untested occupancy aggregate/cleanup paths with a regression test.
2026-10-04 feat(server): track command batch delivery with acks, backoff retry and status API (#2)
    The in-memory CommandQueue existed but nothing ever called it: batches were
    fire-and-forget, so a TV that missed a handoff (offline, CEC timeout) was
    indistinguishable from one that executed it.
    - push_command_batch() now snapshots the connected node set per home as the
    delivery target set and records every attempt
    - device acks settle a batch: complete once all expected nodes ack, retry with
    exponential backoff (2s, 4s) otherwise, dead-letter at max_attempts
    - a background worker started in the lifespan redelivers batches whose window
    elapsed, including batches pushed while every node was offline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
2026-10-04 feat(presence): dwell hysteresis and vacancy release for sensor-driven handoffs (#6)
    A single SLAM frame above threshold switched the TV, so noise, a passer-by or a
    pet could take over the house - and nothing ever stood the TVs down when the
    active room emptied.
    - PresenceTracker (per home, in-memory) requires continuous above-threshold
    reporting for presence_dwell_seconds; switching room or a gap longer than
    presence_dwell_max_gap_seconds restarts the timer
    - waiting reports return reason=dwell with dwell_remaining_seconds; readings are
    still stored and no batch/state/event is touched
    - sustained below-threshold reporting in the active room for
    presence_release_seconds emits a stan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
2026-10-04 feat(ota): firmware rollout tracking with per-node version status (#9)
    Nodes report a firmware version on hello and the server can host a binary, but
    nothing recorded what a home was supposed to be running, so a rollout had no
    definition of 'done'.
    - new FirmwareRollout row per home holding target_version
    - GET/PUT/DELETE /ota/rollout (authenticated; manifest stays unauthenticated)
    report per-node up_to_date / behind / ahead / unknown plus counts
    - versions compare numerically: 0.10.0 is newer than 0.7.0, and +build metadata
    is ignored, so string comparison no longer marks stale nodes as current
    - a version with no numeric content reports unknown instead of being padded to
    zeros and c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
2026-10-04 feat(server): Prometheus /metrics endpoint with HTTP, websocket and batch series (#10)
    The coordinator had diagnostics and an event log but nothing a scraper could
    read, so uptime and delivery health were only observable by reading logs.
    - small in-process registry (counter/gauge/histogram) rendering text format
    0.0.4; hand-rolled to keep the runtime dependency list unchanged
    - MetricsMiddleware counts requests and observes duration, labelled by route
    template rather than raw path so per-UUID cardinality cannot explode
    - GET /metrics exposes build info, device/app websocket connections, command
    batch depth and node liveness; gauges are computed at scrape time so they are
    correct rig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
